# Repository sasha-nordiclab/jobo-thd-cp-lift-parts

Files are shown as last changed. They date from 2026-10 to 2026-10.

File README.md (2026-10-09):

# THD CP-Lift parts

3D-printable parts for working with JOBO drums on the THD CP-Lift. Each part is a parametric FreeCAD model with STEP files and printing notes.

▶ **Videos:** [YouTube playlist](https://www.youtube.com/playlist?list=PLADhkNYpSGAc)

## Downloads

Each link downloads the file directly. STEP files open in any CAD program or slicer. The FCStd files are the parametric FreeCAD models.

| Part | Print files (STEP) | FreeCAD model | Everything in one zip |
|---|---|---|---|
| **Bottle holder** | [Module](https://github.com/sasha-nordiclab/thd-cp-lift-parts/raw/main/bottle-holder/step/THD_CP_Lift_Holder_Module.step) · [Module, mirrored](https://github.com/sasha-nordiclab/thd-cp-lift-parts/raw/main/bottle-holder/step/THD_CP_Lift_Holder_Module_Mirrored.step) · [Nut bar](https://github.com/sasha-nordiclab/thd-cp-lift-parts/raw/main/bottle-holder/step/THD_CP_Lift_Nut_Bar.step) · [Gasket (TPU)](https://github.com/sasha-nordiclab/thd-cp-lift-parts/raw/main/bottle-holder/step/THD_CP_Lift_Gasket_TPU.step) · [Bottle stand (TPU)](https://github.com/sasha-nordiclab/thd-cp-lift-parts/raw/main/bottle-holder/step/THD_CP_Lift_Bottle_Stand_TPU.step) | [FCStd](https://github.com/sasha-nordiclab/thd-cp-lift-parts/raw/main/bottle-holder/cad/THD_CP_Lift_Bottle_Holder.FCStd) | [v1.1 ZIP](https://github.com/sasha-nordiclab/thd-cp-lift-parts/releases/download/bottle-holder-v1.1/bottle-holder-v1.1.zip) |
| **Heater holder** | [Base](https://github.com/sasha-nordiclab/thd-cp-lift-parts/raw/main/heater-holder/step/THD_Heater_Holder_Base.step) · [Cap](https://github.com/sasha-nordiclab/thd-cp-lift-parts/raw/main/heater-holder/step/THD_Heater_Holder_Cap.step) | [FCStd](https://github.com/sasha-nordiclab/thd-cp-lift-parts/raw/main/heater-holder/cad/THD_Heater_Holder.FCStd) | [v1.0 ZIP](https://github.com/sasha-nordiclab/thd-cp-lift-parts/releases/download/heater-holder-v1.0/heater-holder-v1.0.zip) |
| **Drum mount** (experimental) | [Mount](https://github.com/sasha-nordiclab/thd-cp-lift-parts/raw/main/drum-mount/step/JoboDrumMount_Mount.step) · [Lock](https://github.com/sasha-nordiclab/thd-cp-lift-parts/raw/main/drum-mount/step/JoboDrumMount_Lock.step) | [FCStd](https://github.com/sasha-nordiclab/thd-cp-lift-parts/raw/main/drum-mount/cad/JoboDrumMount.FCStd) | [v0.1 ZIP](https://github.com/sasha-nordiclab/thd-cp-lift-parts/releases/download/drum-mount-v0.1/drum-mount-v0.1.zip) |

The whole repository as a zip: [main.zip](https://github.com/sasha-nordiclab/thd-cp-lift-parts/archive/refs/heads/main.zip). Screws, nuts and print settings for each part are in its README.

## Parts

| Part | What it does | Status | Folder |
|---|---|---|---|
| **Bottle holder** | An optimised redesign for this machine: holds four standard JOBO bottles in the water bath. It mounts with stainless countersunk screws through the 3 mm bath wall into a printed nut bar. See the [design report](bottle-holder/docs/report.md); FEM has not been rerun for the latest frame details. | [v1.1 release](https://github.com/sasha-nordiclab/thd-cp-lift-parts/releases/tag/bottle-holder-v1.1) | [`bottle-holder/`](bottle-holder/) |
| **Drum mount** | Holds a JOBO drum on the lift, with a sliding lock and a printed spring. | 🧪 [v0.1 experimental release](https://github.com/sasha-nordiclab/thd-cp-lift-parts/releases/tag/drum-mount-v0.1) | [`drum-mount/`](drum-mount/) |
| **Heater holder** | An ABS clamp that holds the 220 V bath heater horizontally, 15 mm above the bath floor. The base is glued to the floor, and the cap is screwed down with two M4 countersunk Torx screws that form their own thread in the plastic. | [v1.0 release](https://github.com/sasha-nordiclab/thd-cp-lift-parts/releases/tag/heater-holder-v1.0) | [`heater-holder/`](heater-holder/) |

## Shared pump model and accessories

The [ROTEK A01VP repository](https://github.com/sasha-nordiclab/ROTEK-A01VP) holds the parametric reference model of the Rotek circulation pump and compatible accessories, starting with a TPU vibration-damping holder. The same pump is used in the JOBO Repair Parts project. The [FreeCAD model](https://github.com/sasha-nordiclab/ROTEK-A01VP/blob/main/cad/TPU_Pump_Holder.FCStd) contains both the pump and the holder.

<table align="center">
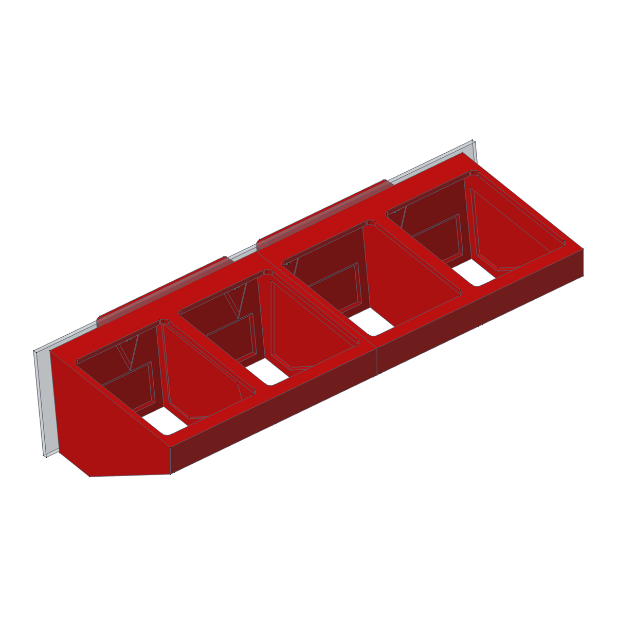
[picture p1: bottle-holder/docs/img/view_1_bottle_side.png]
Bottle holder
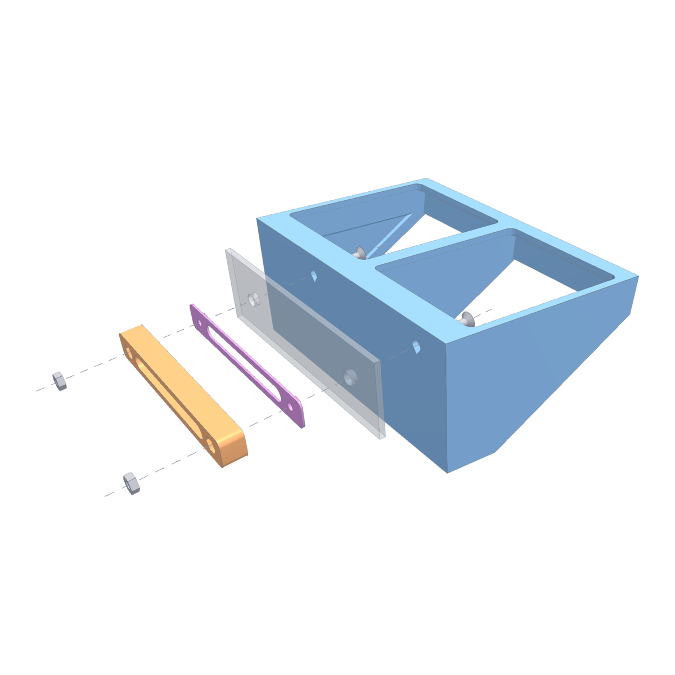
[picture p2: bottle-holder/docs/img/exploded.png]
Exploded view
  <tr><td align="center"><br><b>Bottle holder</b></td><td align="center"><br><b>Exploded view</b></td></tr>
</table>

## Common notes

- **Material:** PETG for the bottle holder and drum mount; ABS for the heater holder.
- **Profile used for the times in each README:** 0.4 mm nozzle, 0.6 mm line width, 0.2 mm layers, 5 walls, OrcaSlicer on a Bambu Lab A1.
- **Models:** made with a FreeCAD 26.3 development build. Older FreeCAD releases may not open them; the STEP files work in any CAD or slicer.
- **Changing sizes:** every model is driven by a spreadsheet (`params` or `Params`). Change the values there and recompute.

## License

[CC BY-NC-SA 4.0](LICENSE). You may share and adapt these designs with attribution, not for commercial use, and under the same license.

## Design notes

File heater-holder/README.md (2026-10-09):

# THD heater holder — ABS clamp

A two-part clamp that holds the 220 V THD bath heater horizontally on the bath floor. The base is glued to the floor. The cap is pulled down onto the soft rubber head of the heater by two M4 screws. The clamp has no snap, so thermal swell of the head or the plastic does not matter.

**Release:** [v1.0](https://github.com/sasha-nordiclab/thd-cp-lift-parts/releases/tag/heater-holder-v1.0). [Download the complete ZIP](https://github.com/sasha-nordiclab/thd-cp-lift-parts/releases/download/heater-holder-v1.0/heater-holder-v1.0.zip).

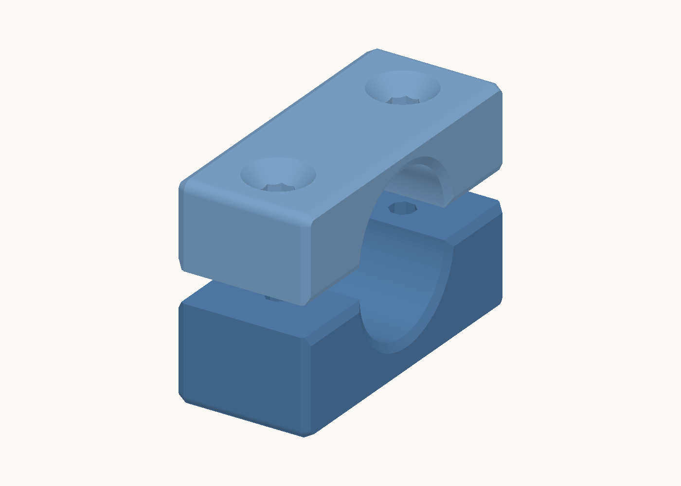
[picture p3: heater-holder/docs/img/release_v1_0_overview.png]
Heater clamp base and cap
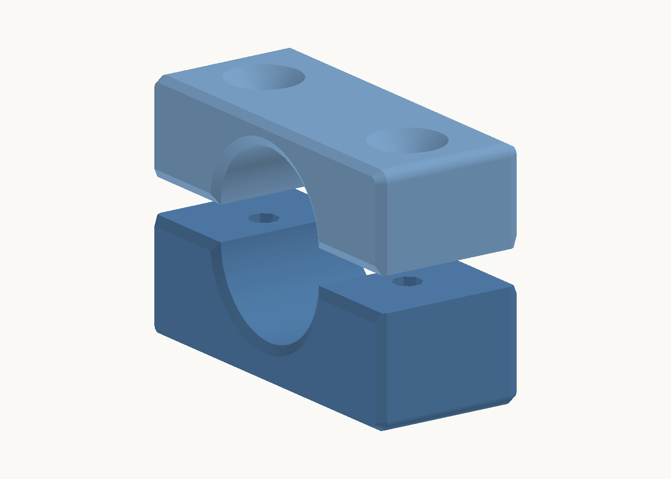
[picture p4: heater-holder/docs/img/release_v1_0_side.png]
Heater clamp from the side


⬇️ **Download:** [Base](https://github.com/sasha-nordiclab/thd-cp-lift-parts/raw/main/heater-holder/step/THD_Heater_Holder_Base.step) · [Cap](https://github.com/sasha-nordiclab/thd-cp-lift-parts/raw/main/heater-holder/step/THD_Heater_Holder_Cap.step) · [FreeCAD model](https://github.com/sasha-nordiclab/thd-cp-lift-parts/raw/main/heater-holder/cad/THD_Heater_Holder.FCStd)

## Model

**Working model:** [THD_Heater_Holder.FCStd](cad/THD_Heater_Holder.FCStd), rebuilt from scratch with `python3 scripts/build.py` (fdmkit over RPC). All sizes are in the `params` spreadsheet.

- Body **Heater**: a reference mock-up. The rod is Ø16 × 110, the rubber head Ø20 × 20.
- Body **Base**: glued to the floor, with a half-round bed for the head.
- Body **Cap**: a plain block with a half-round bore, screwed onto the base.
- **Screw** is an M4 × 25 ISO 14581 (countersunk Torx) from the Fasteners workbench. **Screw_Mirror** is an `App::Link` to it.

### How the model is built

Both parts are symmetric about the vertical plane through the heater axis. Each one is modelled as its +Y half and mirrored once:

| Step | Base | Cap |
|---|---|---|
| 1. Half profile sketch | `s_b_half`: block with a corner round and the half bed | `s_k_half`: block with a corner round and the half bore |
| 2. Pad, symmetric, `c_len` | `b_half` | `k_half` |
| 3. Screw hole on +Y | `b_pilot`: octagonal pilot | `k_oct` and `k_hole`: octagon and countersink (PartDesign Hole) |
| 4. End-face chamfers | `b_bed_chamfer`, `b_top_chamfer` | `k_bed_chamfer`, `k_top_chamfer` |
| 5. Mirror the whole half across XZ | `b_mirror` | `k_mirror` |

The constraints in the half-profile sketches carry readable names, such as `axis_z`, `half_width`, `bore_r` and `cap_top`.

Every sketch is fully constrained, and every size comes from the `params` spreadsheet. Change a value there and recompute. Checked with a 24 mm head, a 25 mm head length, an 18 mm axis height and a 54 mm width.

### Coordinates

- z = 0 is the bath floor, which is also the base's glue face.
- The heater axis runs along X at `ax_z` = 15 mm.
- x = 0 is the joint between head and rod. The head is at x −20…0, the rod at x 0…110.

### Clamp

| | |
|---|---|
| Length along the axis | `c_len` = the full head length, 20 mm |
| Bore | Ø19.8 (`c_fit` 0.2 undersize), split at the axis with a `k_gap` 0.6 mm gap |
| Base | a solid block, 46 × 20 mm on the floor and 14.7 mm high, with a half-round bed |
| Cap | a plain block, 46 × 20 × 12.6 mm, with a half-round bore. Together with the base it makes one rectangular block split at the axis. The outer corners have an R1.5 round (`k_er`) |
| Screws | 2 × M4 × 25 ISO 14581, 304 stainless, at ±14.5 mm. The heads sit flush in 90° countersinks (Ø9.6) |
| Thread | the screws form their own thread in octagonal blind pilot holes in the base: 3.5 mm across flats, 13 mm deep. The screw bites into the flats, and the corners take the chips. Engagement is 11.8 mm |

Tightening the screws closes the gap, so the rubber head is squeezed by about 0.8 mm in height.

The heater bottom is 5 mm above the floor and the rod bottom 7 mm, so water flows under the rod.

## Files

- [cad/THD_Heater_Holder.FCStd](cad/THD_Heater_Holder.FCStd) is the parametric model.
- [`step/`](step/) holds the STEP files of the base and the cap.
- [scripts/build.py](scripts/build.py) rebuilds the model in a running FreeCAD through fdmkit.

## Print

ABS (AzureFilm ABS Plus), profile "0.20mm NordicLab 0.6 Ballance", 100 % zig-zag, Bambu A1:

| Part | Orientation | Time | Mass |
|---|---|---|---|
| Base | on its end face x = −20 (profile on the bed) | 36 min 0 s | 10.2 g |
| Cap | on its end face x = −20 (profile on the bed) | 32 min 30 s | 7.9 g |

ABS warps on the open A1. Both parts have a plain rectangular outline with rounded outer corners. Use a brim.

Every edge of both end faces has a chamfer: 1.2 mm along the print vertical at 30° from vertical, so 0.69 mm on the face (`e_h`, `e_a`). On the bed face it prevents elephant foot. The four outer corners of the block are rounded with R1.5 (`k_er`); they run along the print vertical.

All screw holes are octagons, with a flat facing up in the end-face print: a short bridge (< 2 mm) on top and 45° sides. The cap clearance holes are 4.5 mm across flats. The upper part of the 90° countersink is 45° from vertical, which is slightly over the 40° limit, but it is only about 2.5 mm deep.

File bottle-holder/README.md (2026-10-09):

# THD CP-Lift bottle holder

**Release:** [v1.1](https://github.com/sasha-nordiclab/thd-cp-lift-parts/releases/tag/bottle-holder-v1.1) has the latest pair of frames. The [v1.0 release](https://github.com/sasha-nordiclab/thd-cp-lift-parts/releases/tag/bottle-holder-v1.0) is archived.

⬇️ **Download:** [Module](https://github.com/sasha-nordiclab/thd-cp-lift-parts/raw/main/bottle-holder/step/THD_CP_Lift_Holder_Module.step) · [Module, mirrored](https://github.com/sasha-nordiclab/thd-cp-lift-parts/raw/main/bottle-holder/step/THD_CP_Lift_Holder_Module_Mirrored.step) · [Nut bar](https://github.com/sasha-nordiclab/thd-cp-lift-parts/raw/main/bottle-holder/step/THD_CP_Lift_Nut_Bar.step) · [Gasket (TPU)](https://github.com/sasha-nordiclab/thd-cp-lift-parts/raw/main/bottle-holder/step/THD_CP_Lift_Gasket_TPU.step) · [Bottle stand (TPU)](https://github.com/sasha-nordiclab/thd-cp-lift-parts/raw/main/bottle-holder/step/THD_CP_Lift_Bottle_Stand_TPU.step) · [FreeCAD model](https://github.com/sasha-nordiclab/thd-cp-lift-parts/raw/main/bottle-holder/cad/THD_CP_Lift_Bottle_Holder.FCStd) · [v1.1 ZIP](https://github.com/sasha-nordiclab/thd-cp-lift-parts/releases/download/bottle-holder-v1.1/bottle-holder-v1.1.zip)

An optimised redesign of the bottle holder, reworked for the THD CP-Lift. It holds **four standard JOBO bottles** in the water bath.

- It mounts with stainless steel countersunk screws through the 3 mm bath wall. A printed nut bar on the outside of the bath holds the nuts.
- Each module holds two bottles. Print one **Module**, one **Module mirrored**, two **Nut bars** (PETG), two **Gaskets** and four **Bottle stands** (TPU).

▶ **Videos:** [YouTube playlist](https://www.youtube.com/playlist?list=PLADhkNYpSGAc)

<table align="center">
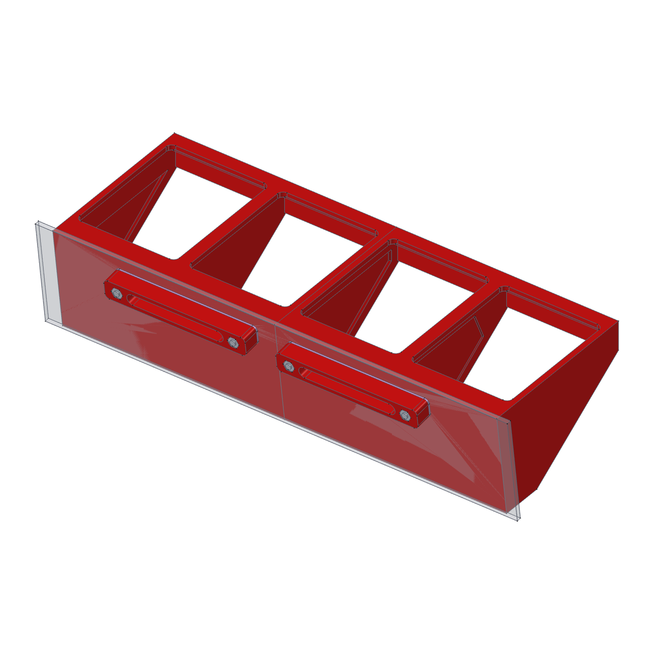
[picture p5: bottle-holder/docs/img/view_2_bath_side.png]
Bath side
  <tr><td align="center">Bottle side<br><b>Bottle side</b></td><td align="center"><br><b>Bath side</b></td></tr>
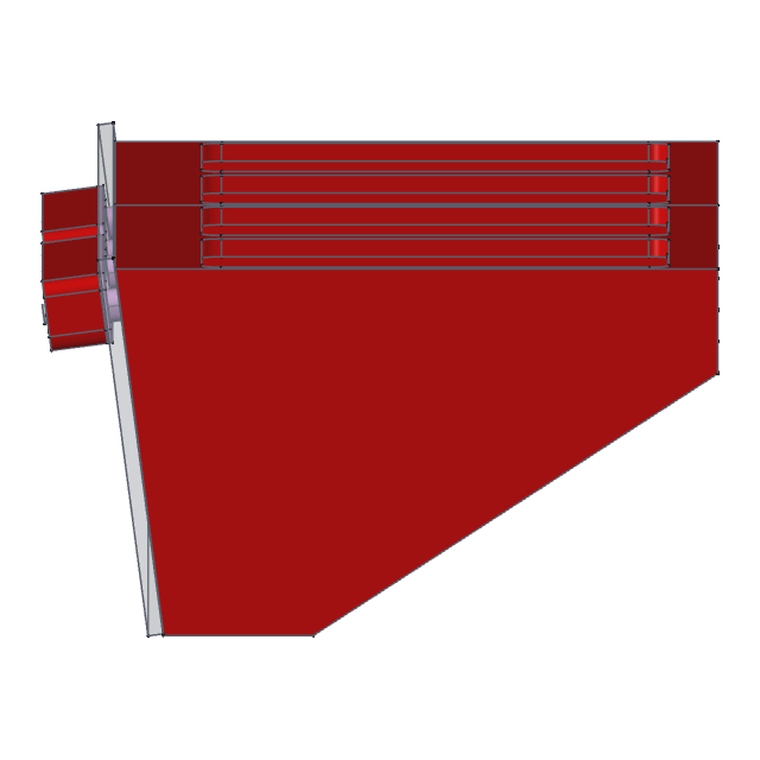
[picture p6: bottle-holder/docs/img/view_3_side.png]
Side
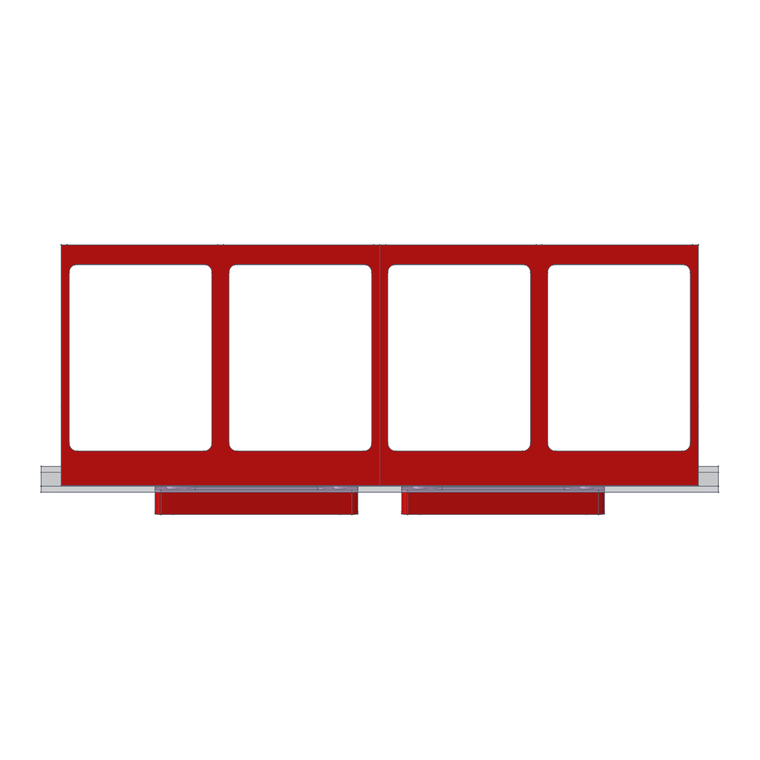
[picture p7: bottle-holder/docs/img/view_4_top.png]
Top
  <tr><td align="center"><br><b>Side</b></td><td align="center"><br><b>Top</b></td></tr>
</table>

Latest frame geometry: [isometric view](docs/img/release_v1_1_overview.png) · [top view](docs/img/release_v1_1_top.png).

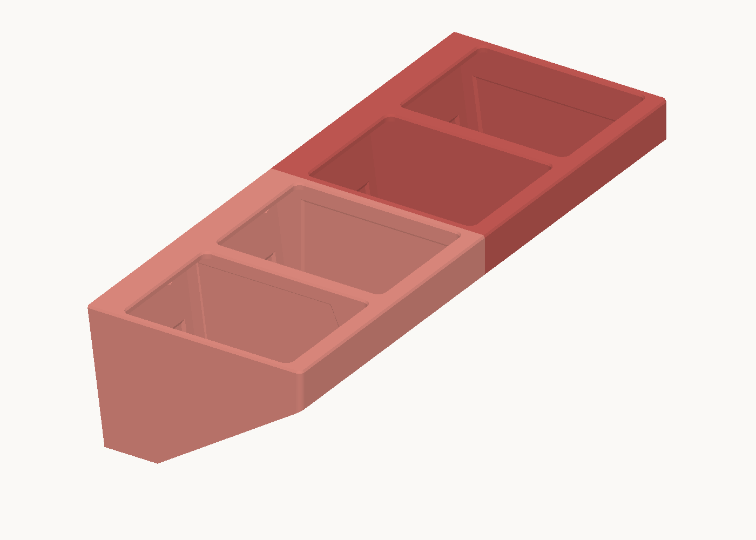
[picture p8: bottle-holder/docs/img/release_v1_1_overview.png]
Current four-bottle frame, made from two mirrored modules


| | Per module |
|---|---|
| Size | 120.4 × 159.5 × 74.7 mm |
| Bottle opening | 93.4 × 71.4 mm, corner radius 4 mm (×2) |
| Mounting | 2 × M4 × 20 countersunk Torx screws (304 stainless) + 2 nuts in a nut bar |
| Material | PETG |
| Mass / print time | ≈ 126 g / ≈ 3 h (solid, see [Printing](#printing)) |

## Files

| Path | What |
|---|---|
| `cad/THD_CP_Lift_Bottle_Holder.FCStd` | Parametric FreeCAD model: bodies `Module`, `Nut_Bar`, `Gasket`, `Bottle_Stand`, the mirrors, and an `Assembly` with the screws, nuts and a reference bath |
| `step/THD_CP_Lift_Holder_Module.step` | Module, for slicing or other CAD |
| `step/THD_CP_Lift_Holder_Module_Mirrored.step` | Mirrored module |
| `step/THD_CP_Lift_Nut_Bar.step` | Nut bar; print two, the same part fits both modules |
| `step/THD_CP_Lift_Gasket_TPU.step` | Gasket under the nut bar; print two in TPU 95A |
| `step/THD_CP_Lift_Bottle_Stand_TPU.step` | Bottle stand glued to the bath floor; print four in TPU 95A |
| `docs/report.md` | Design report: how it works, assembly, calculations, FEM pictures |
| `docs/strength.md` | How the part was checked and why it looks the way it does |
| `scripts/fem/` | The strength calculation (CalculiX), for the default size |

## Printing

- **Orientation:** frame face down on the bed. The top face is flat, and nothing is steeper than 40° except the small screw countersinks. No supports are needed.
- **Profile:** PETG, 0.4 mm nozzle, 0.6 mm line width, 0.2 mm layers, 5 walls.
- **Infill:** **100 %, rectilinear (zig-zag).**
  - The walls are 1.8–3 mm thick and the strength check assumes solid plastic.
  - 5 walls of 0.6 mm fill the 3 mm walls exactly, and 100 % infill makes the 3.6 mm frame solid.
  - On thin-walled parts like this, 100 % rectilinear was faster than 40 % cubic.
- **Result:** in OrcaSlicer on a Bambu Lab A1, about 3 h 05 min and 126 g per module.

| Part | Qty | Material | Orientation | Time / mass each |
|---|---|---|---|---|
| Module, Module mirrored | 1 + 1 | PETG | frame face down | ≈ 3 h 05 min, 126 g |
| Nut bar | 2 | PETG | bath side down, nut pockets up | ≈ 32 min, 11 g |
| Gasket | 2 | TPU 95A | flat, sleeves up, 100 % | ≈ 12 min, 1 g |
| Bottle stand | 4 | TPU 95A | glue face down | ≈ 1 h 16 min, 11 g |

## Bottle stands

A small TPU stand under each bottle, glued to the floor of the bath. The bottle rests on it instead of on the bath floor, so water flows under and around the bottle.

- Rounded frame 45 × 35 mm, 20 mm tall, 2.4 mm walls, with a cross inside.
- **Glue face:** a solid 1.2 mm base, about 1540 mm² of flat surface. The stand is printed on this face, so it is flat and ready for glue.
- **Water flow:** every wall and the cross have windows from the top of the base up to 13 mm. No cell is closed, so water flows straight through and nothing is trapped when the bath is drained.
- The windows have 45° pointed tops, so TPU prints them without supports.
- Position: centred under each bottle opening; the stand's base is 145 mm below the top of the frame (`stand_drop`).
- All sizes are in `params`: `stand_dx`, `stand_dy`, `stand_h`, `stand_r`, `stand_w`, `stand_base`, `stand_win_top`, `stand_drop`.

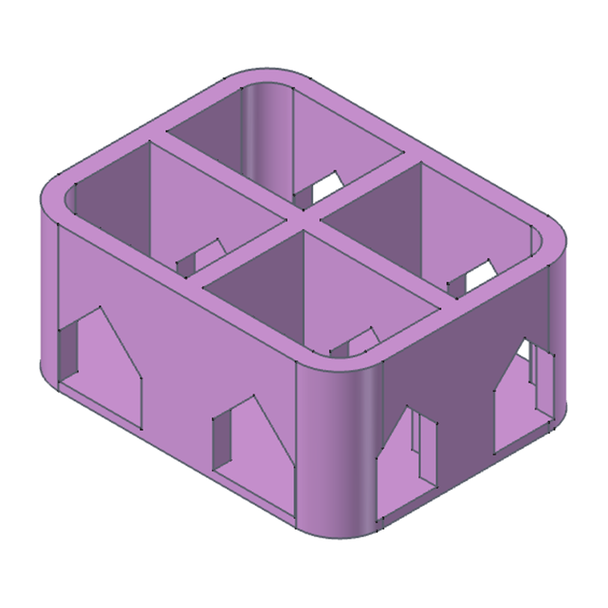
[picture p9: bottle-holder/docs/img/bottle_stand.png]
TPU bottle stand


## Assembly in the model

The FreeCAD file contains an `Assembly` (Assembly workbench) with both modules, the nut bars, the gaskets, the four stands, 4 × M4 × 20 ISO 14581 screws, 4 × M4 ISO 4032 nuts, and a reference bath wall and floor.
- Every position follows the spreadsheet, including the wall tilt, the screw length and the stand depth.
- The screws and nuts come from the **Fasteners** workbench; install it from the Addon Manager to open the assembly.
- In the Fasteners objects the screw length is a fixed 20 mm. If you change `bolt_len`, change it there too.

## Mounting

<p align="center">Exploded view: holder, bath wall, TPU gasket, nut bar, nuts</p>

<p align="center"><a href="docs/img/exploded.mp4">▶ Explode animation</a></p>

**Per module you need:**
- 2 × **M4 × 20 countersunk Torx screws**, 304 stainless (ISO 14581, 90° head Ø 8.4 mm). They fit the Ø 9.2 mm countersink.
- 2 × **M4 nuts** ISO 4032, stainless.
- 1 × **printed nut bar**.
- 1 × **TPU gasket** (between the bath and the nut bar).

The screws go in from the bottle side, through the holder and the bath's Ø 6.6 mm holes. The nuts sit in the hex pockets of the nut bar on the outside of the bath.

**The stack along the screw:**

| Part of the stack | mm |
|---|---|
| Head top to the holder's mounting face | 4.0 |
| Bath wall | 3.0 |
| TPU gasket | 1.0 |
| Nut bar under the nut | 7.9 |
| Nut ISO 4032, flush in its pocket | 3.2 + 0.2 |
| Screw tip past the nut | 0.9 |
| **Total** | **20** |

The nut bar is sized to the screw. `bolt_len` in the spreadsheet sets the screw length, and the bar thickness follows (11.3 mm for M4 × 20 with the 1 mm gasket, at least 5.4 mm). The tip then ends just past the nut and does not stick out behind the bath; `bolt_tip` shows the overhang.

- **Sealing the bath holes.** A flat 1 mm TPU 95A gasket with the same outline as the nut bar goes between the bar and the outside of the bath wall. Tightening squeezes it.
  - A Ø 6.3 mm sleeve on the gasket goes into each Ø 6.6 mm bath hole; the screw passes through a Ø 4.2 mm hole in it.
  - The holder itself is unchanged, so its strength check still applies. The bath pressure is tiny (0.01–0.02 bar).
  - Print the gasket flat, sleeves up, 100 % infill.
- The bath holes are a standard M6 clearance (6.6 mm). The M4 screws have play in them, but the countersunk heads and the nut bar hold everything in place.
- The rear face of the holder is tilted 7.5° to sit flat on the bath wall.
- Each bottle's side rib catches the ledge under the front of the frame, so a floating bottle cannot lift out.
- The nut bar has a through slot between the nuts, so material stays only where the nuts press; `slot_w` and `slot_off` set it.
- Print the nut bar flat, bath side down, with the pockets facing up: about 32 min and 11.4 g.

## Adapting it to other bottles

Open the model in FreeCAD and edit the spreadsheet `params`. Everything else, including the nut bar, follows these five values:

| Parameter | Default | Meaning |
|---|---|---|
| `open_x` | 93.4 | bottle opening, rear to front |
| `open_y` | 71.4 | bottle opening, side to side |
| `open_r` | 4 | opening corner radius |
| `web_h` | 70.5 | depth of the side walls below the frame |
| `lip_h` | 18 | depth of the front wall |

**Bath wall tilt.** If your bath wall leans differently, change `rear_tilt` (default 7.5°, 0 = vertical). The whole rear wall, the frame edge, the screw holes and bosses, the recesses, the nut bar and the gasket all follow. Rebuilds were checked at 0°, 3°, 7.5°, 10° and 15°: the mounting face stays one flat plane and the screw length is unchanged.

What follows automatically:
- the bay pitch, module length, frame, recesses, screw positions and the mirror;
- recesses switch themselves off when their zone gets too small;
- the screws keep clear of the walls.

**Other parameter groups in `params`:**
- **Build:** wall and frame thickness, gaps.
- **Mount:** wall tilt, screw positions, bosses.
- **Lightening:** recess depths (0 = none).
- **Nut bar:** bath wall, nut size, bar thickness and width, plus the screw length `bolt_len`.

Do not edit the **Derived** cells.

These sizes were rebuilt and checked: 50 × 40 / 35 mm, 60 × 45 / 45 mm, 75 × 60 / 60 mm, 100 × 80 / 80 mm, and 2.4 mm walls. In every case the result is one valid solid with clear screw holes. **Strength was calculated only for the default size**; check yours before relying on it.

The model was made with a FreeCAD 26.3 development build. Older FreeCAD releases may not open it; the STEP files work anywhere.

## Strength

The finite-element calculation predates the latest hole layout and frame chamfer; it has not been rerun for this revision.

Checked by finite elements (CalculiX) with real supports:
- the screw heads clamp the countersinks;
- the rear wall can push on the lift wall but not pull;
- the material is treated as layered PETG, so layers can peel apart.

Loads:
- floating empty bottles, sustained, safety factor 4;
- a full 0.7 kg bottle knocked into the part at 0.5 m/s, safety factor 2.

| Load case | Load / allowable |
|---|---|
| Floating bottles (sustained) | 0.31 ✅ |
| Bottle hits the frame from above | 1.08 |
| Bottle hits the front edge | 1.17 |
| Bottle hits the divider sideways | 1.75 |

- A value of 1.0 or less passes with the full safety factor.
- Values up to 2 use part of the safety factor of 2 but stay below the material strength. The worst case is a sideways knock on the divider, at the corner of the opening.
- The front ledge and overall layout come from a holder that is already in use.

Deformation under each load, strongly exaggerated (colour = deflection, arrows = load):

<table align="center">
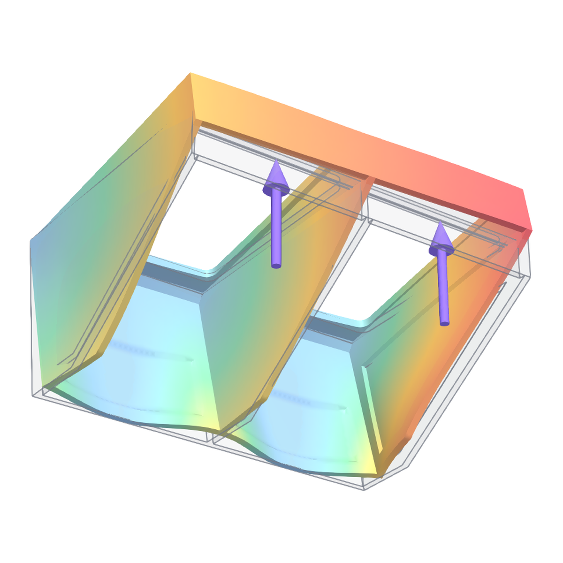
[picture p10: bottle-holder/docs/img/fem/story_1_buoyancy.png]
Floating bottles
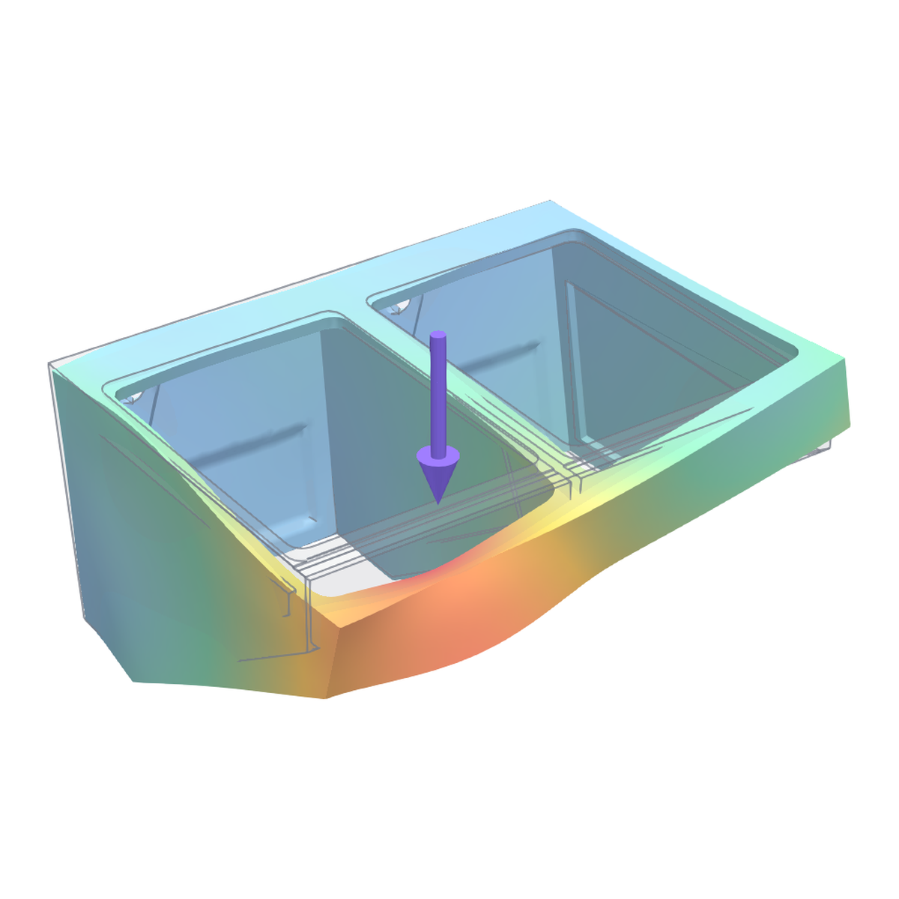
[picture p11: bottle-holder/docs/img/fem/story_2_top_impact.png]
Hit from above
  <tr><td align="center"><br><b>Floating bottles</b></td><td align="center"><br><b>Hit from above</b></td></tr>
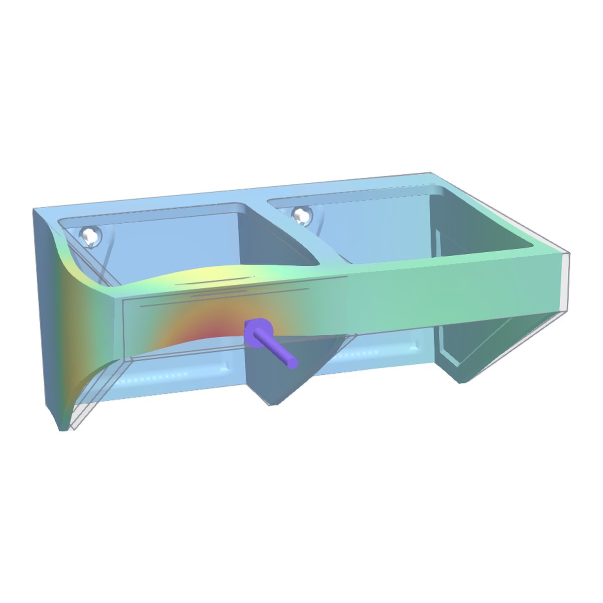
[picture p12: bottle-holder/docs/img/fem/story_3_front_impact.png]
Hit on the front edge
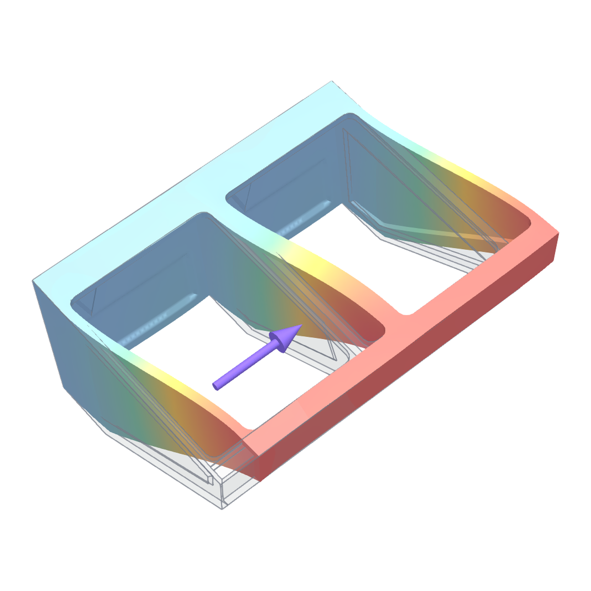
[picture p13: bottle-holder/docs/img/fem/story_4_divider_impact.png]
Hit on the divider
  <tr><td align="center"><br><b>Hit on the front edge</b></td><td align="center"><br><b>Hit on the divider</b></td></tr>
</table>

<p align="center"><a href="docs/img/fem/loads_story.mp4">▶ Animation of all four load cases</a></p>

The full design report (how it works, exploded view, screw and seal calculations, deformation pictures) is in [docs/report.md](docs/report.md). The method, the design changes and the rejected variants are in [docs/strength.md](docs/strength.md).

## License

[CC BY-NC-SA 4.0](../LICENSE): you may share and adapt this design with attribution, not for commercial use, and under the same license.

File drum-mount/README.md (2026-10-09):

# JOBO drum mount for the THD CP-Lift

> [!WARNING]
> **Experimental, work in progress.** The geometry may change, and it has not been strength-checked. Print and use it at your own risk.

**Experimental release:** [v0.1](https://github.com/sasha-nordiclab/thd-cp-lift-parts/releases/tag/drum-mount-v0.1). [Download the complete ZIP](https://github.com/sasha-nordiclab/thd-cp-lift-parts/releases/download/drum-mount-v0.1/drum-mount-v0.1.zip).

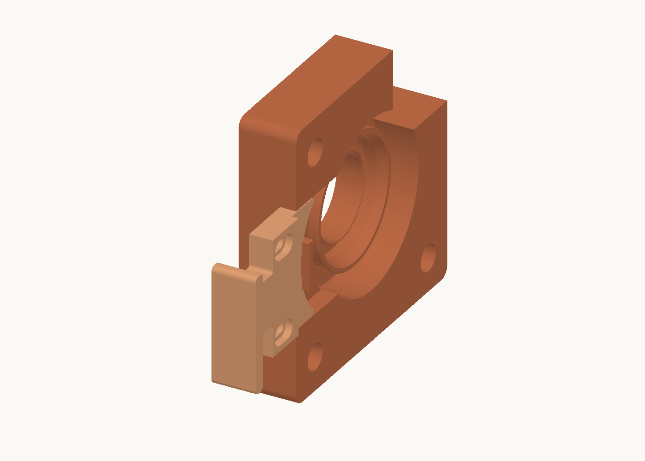
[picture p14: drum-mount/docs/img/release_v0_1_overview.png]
Drum mount and sliding lock
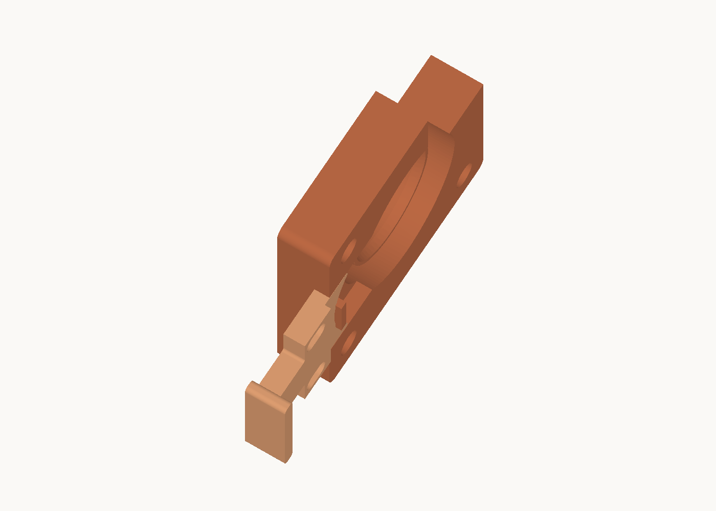
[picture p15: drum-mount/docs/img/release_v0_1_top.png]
Drum mount and lock from above


⬇️ **Download:** [Mount](https://github.com/sasha-nordiclab/thd-cp-lift-parts/raw/main/drum-mount/step/JoboDrumMount_Mount.step) · [Lock](https://github.com/sasha-nordiclab/thd-cp-lift-parts/raw/main/drum-mount/step/JoboDrumMount_Lock.step) · [FreeCAD model](https://github.com/sasha-nordiclab/thd-cp-lift-parts/raw/main/drum-mount/cad/JoboDrumMount.FCStd)

A two-part mount that holds a JOBO drum on the THD CP-Lift:
- **Mount** — an 80 × 80 mm plate with locating rings, a Ø 24 mm centre bore and a pocket for the motor.
- **Lock** — a sliding latch with a printed spring. To release the drum, pull the finger ears; the spring pushes the latch back. Travel is 3.5 mm.

| Part | Size | Print (PETG, see below) |
|---|---|---|
| Mount | 80 × 80 × 19 mm | ≈ 2 h, 60 g (40 % infill) / 85 g (solid) |
| Lock | 45 × 34 × 13 mm | ≈ 25 min, 8 g |

## Files

| Path | What |
|---|---|
| `cad/JoboDrumMount.FCStd` | Parametric FreeCAD model: bodies `Mount` and `Lock`, the final `LockMirror` feature, and an assembly that shows how they fit |
| `step/JoboDrumMount_Mount.step` | Mount |
| `step/JoboDrumMount_Lock.step` | Lock, exported from `LockMirror` |

## Printing

- Both parts print flat on their largest face, with no supports.
- PETG, 0.4 mm nozzle, 0.6 mm line width, 0.2 mm layers, 5 walls.
- The times above are from OrcaSlicer on a Bambu Lab A1. The Mount at 40 % cubic is enough for normal use; print it solid if you want it stiffer.

## Assembly

- **Mount to the lift:** three screws through Ø 4.5 mm holes with Ø 8 mm counterbores, 4.4 mm deep. M4 cap screws fit.
- **Lock to the Mount:** two screws through the Lock's slots into Ø 2.9 mm pilot holes in the Mount. M3 screws tap into them.

## Parameters

All sizes are in the spreadsheet `Params`. Cells starting with `D_` are derived; do not edit them.

| Parameter | Default | Meaning |
|---|---|---|
| `PLATE_W`, `PLATE_T`, `PLATE_R` | 80, 5, 3 | plate width, thickness, corner radius |
| `RING_OD`, `RING_ID`, `RING_H` | 39, 34, 7 | locating ring |
| `RING2_OD`, `RING2_H` | 26, 3 | inner ring |
| `BORE_D` | 24 | centre bore |
| `RECESS_D`, `FRAME_H` | 50, 12 | drum recess diameter, frame height |
| `MOTOR_OFS`, `MOTOR_POCKET_R` | 31.5, 11 | motor pocket position and radius |
| `HOLE_OFS`, `HOLE_D`, `HOLE_CB_D`, `HOLE_CB_DEPTH` | 30, 4.5, 8, 4.4 | mounting holes |
| `SLOT_W`, `LOCK_CLR`, `LOCK_TRAVEL` | 35, 0.3, 3.5 | lock slot width, clearance, travel |
| `SPRING_T`, `SPRING_PRE` | 1.3, 0.5 | spring strip thickness, preload |
| `LOCK_SCREW_PITCH`, `LOCK_SCREW_HOLE_D` | 25, 2.9 | lock screws |

## License

[CC BY-NC-SA 4.0](../LICENSE).

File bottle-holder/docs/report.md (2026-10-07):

# THD CP-Lift bottle holder — design report

Revision: 2026-10-06. Covers the bottle holder, its mounting (nut bar, TPU gasket, screws) and the checks behind each decision.

<p align="center">Two modules on the bath wall: four bottles</p>

## 1. Summary

**What it is.** A printed holder for **four standard JOBO bottles** in the water bath of the THD CP-Lift.
- It is made of two modules: a **Module** and its mirror image. Each holds two bottles.
- Each module screws through the 3 mm bath wall with two stainless countersunk screws.
- On the outside of the bath, a printed **nut bar** holds the nuts and a **TPU gasket** seals the holes.

**Key numbers per module:**

| | |
|---|---|
| Size | 120.4 × 159.5 × 73.5 mm |
| Holder | 102.6 cm³, ≈ 126 g PETG, ≈ 3 h 05 min (solid) |
| Nut bar | 101.5 × 14 × 11.3 mm, ≈ 11 g PETG, ≈ 32 min |
| Gasket | 1 mm TPU 95A, ≈ 1 g |
| Hardware | 2 × M4 × 20 countersunk Torx (304 stainless), 2 × M4 nut ISO 4032 |
| Strength (load / allowable, ≤ 1 passes) | floating bottles **0.31** ✅; knocks by a full bottle 1.08–1.75 (see §5) |

## 2. How it works

<p align="center">Exploded view: holder, bath wall, TPU gasket, nut bar, nuts</p>

[Explode animation](img/exploded.mp4)

**Holding the bottles.**
- Each bottle drops through a rounded opening in the top frame.
- Its side rib catches a ledge under the front edge of the frame.
- An empty or half-full bottle floats in the bath. Buoyancy pushes the rib up against the ledge, so the bottle cannot lift out.

**Carrying the load into the bath wall.**
- The holder is a shelf hanging on the bath wall. The bottle loads push the front down or up, and that creates a moment at the wall.
- The moment is carried in two ways: the two screws near the top hold the holder against the wall, and the rear face bears on the wall over its whole height.
- The rear face is one flat surface tilted 7.5°, the same angle as the bath wall, from the bottom of the holder to the top of the frame. The holder therefore bears on the bath wall everywhere and never rocks on an edge.

**The screw joint.** The parts along each screw, from the inside of the bath to the outside:
1. **Screw head.** A countersunk head sits in a 90° Ø 9.2 mm countersink in a teardrop-shaped boss on the holder's rear wall. The boss spreads the screw load downwards, away from the thin wall.
2. **Holder rear wall.** About 4.4 mm of plastic along the screw.
3. **Bath wall.** 3 mm thick, with Ø 6.6 mm holes (M6 clearance). The M4 screw has play there; the clamped joint, not the hole, holds the position.
4. **TPU gasket.** 1 mm thick, the same outline as the nut bar. Its sleeves fill the bath holes from outside, and tightening squeezes it flat against the bath, which seals the holes.
5. **Nut bar.** A PETG bar with hex pockets for the nuts. It spreads the clamp over the bath wall, bridges the Ø 6.6 mm holes and holds the nuts while the screws are turned. A slot between the nuts removes material that carries no load.
6. **Nut.** An M4 ISO 4032 nut, flush in its pocket. The screw tip ends 0.9 mm past it, so nothing sharp sticks out behind the bath.

**Mirrored modules.** The second module is a mirror image, not a copy: its screws sit at mirrored positions. In the CAD file the mirror is generated from the Module, so a change to one updates both. The nut bar and gasket are symmetric, so the same parts fit both modules.

## 3. Parts and hardware

| Part | Qty (4 bottles) | Material | Print |
|---|---|---|---|
| Module | 1 | PETG | frame face down, 5 walls, 100 % zig-zag: ≈ 3 h 05 min, 126 g |
| Module mirrored | 1 | PETG | same |
| Nut bar | 2 | PETG | bath side down, pockets up: ≈ 32 min, 11 g |
| Gasket | 2 | TPU 95A | flat, sleeves up, 100 % |
| Bottle stand | 4 | TPU 95A | glue face down: ≈ 1 h 16 min, 11 g; glued to the bath floor under each bottle |
| Countersunk Torx screw M4 × 20, 304 stainless | 4 | — | — |
| Nut M4 ISO 4032, stainless | 4 | — | — |

The print times are from OrcaSlicer on a Bambu Lab A1: 0.4 mm nozzle, 0.6 mm lines, 0.2 mm layers.

## 4. Assembly

1. Push a gasket onto the outside of the bath wall, with its sleeves in the two holes.
2. Put the nuts into the hex pockets of the nut bar and hold the bar against the gasket.
3. From the bath side, put the holder against the wall and insert the screws through the holder, the bath, the gasket and the bar.
4. Tighten to about **0.5 N·m**: snug with a screwdriver, no force. See §6 for why.
5. Repeat with the mirrored module.
6. After the first warm-up of the bath, check the screws again. PETG settles slightly at 38 °C.

## 5. Strength of the holder (FEM)

**Model.**
- Second-order tetrahedra (Gmsh), solved in CalculiX. PETG: E = 2200 MPa, ν = 0.38.
- **Screws:** the countersink under each head is held fixed. A tightened screw keeps the joint closed (§6), so the seat acts as bonded.
- **Bath wall:** a rigid plate on the tilted mounting plane. The holder's rear face is in frictionless contact with it (CalculiX node-to-surface contact): the wall can push the holder but cannot pull it.
- **Failure criterion:** layered PETG, printed frame-down:

```
FI = sqrt( (σ_vM,in-plane / 40)² + (max(σ_zz, 0) / 20)² + (τ_interlayer / 15)² )    [MPa]
```

  - Strengths are reduced by 0.85 for the 38 °C bath.
  - Safety factor 4 for the sustained load, 2 for knocks.
  - The tables give the load divided by the allowable: **1.0 or less passes**.
- **Knocks:** a full 0.7 kg bottle at 0.5 m/s carries E = 87.5 N·mm. The force follows from the stiffness k at the point of impact: F = √(2 E k).

**Loads and results:**

| Case | Force | Stiffness | Deflection | Load / allowable | Where, failure mode |
|---|---|---|---|---|---|
| Floating bottles, sustained | 2 × 5.9 N up | — | 0.26 mm | **0.31** ✅ | lower rear wall below screw 2; layer peel |
| Full bottle hits the frame from above | 172 N | 169 N/mm | 1.0 mm | 1.08 | rear wall 6 mm beside screw 1; layer peel |
| Full bottle hits the front edge | 136 N | 105 N/mm | 1.3 mm | 1.17 | frame at the front edge; in-plane |
| Full bottle hits the divider sideways | 58 N | 19 N/mm | 3.0 mm | 1.75 | corner of the bottle opening; in-plane |

**What the numbers mean.**
- The sustained load uses less than a third of the allowable, so the holder does not creep in warm water.
- Knocks use part of the safety factor of 2. Even the worst one, 1.75, stays below the material strength: about 0.9 of what warm PETG takes.
- The divider is the softest place: it is a thin wall loaded sideways. A careless sideways knock is the one case to avoid.

**Check of the calculation.** For every case the forces balance:
- applied load + screw reactions + wall reaction = 0;
- the wall reaction points exactly along the wall normal (z/x = 0.1317 = tan 7.5°), as it must without friction.

The floating case stalled at 58 % of the load (one node kept flipping between touching and not touching). Frictionless contact with no initial gap is proportional to the load, so the last converged step was scaled to the full load.

**Correction to earlier results.** An earlier version of the calculation found only 204 nodes on the rear face, out of 10 743: the search tolerance was too tight and the tilt was 7.547° instead of 7.5°. The wall then held the holder on a narrow strip only, so the holder seemed much softer and weaker (hit from above 1.98, floating 0.86). With the whole face in contact, the holder is stiffer. A knock therefore produces a larger force (172 N instead of 43 N), but the stress is lower.

<table align="center">
  <tr><td align="center">Floating bottles<br><b>Floating bottles</b></td><td align="center">Hit from above<br><b>Hit from above</b></td></tr>
  <tr><td align="center">Hit on the front edge<br><b>Hit on the front edge</b></td><td align="center">Hit on the divider<br><b>Hit on the divider</b></td></tr>
</table>

The pictures show the deformed shape, strongly exaggerated, over the undeformed outline. Colour shows deflection, from blue (none) to red (most). The arrows mark the load.

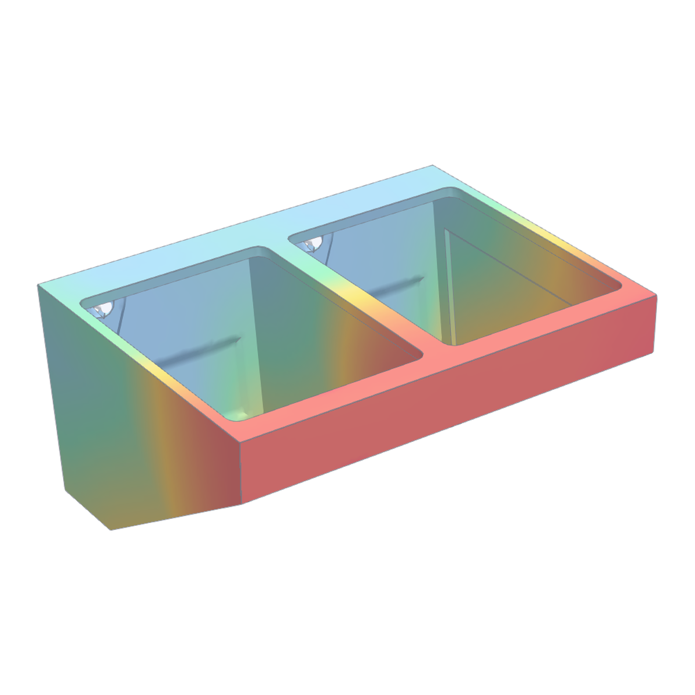
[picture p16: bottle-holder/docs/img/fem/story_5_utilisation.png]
Deflection envelope of all four cases


[Animation of the four load cases](img/fem/loads_story.mp4)

All numbers: [`fem_results.json`](fem_results.json). Method in detail: [`strength.md`](strength.md).

## 6. Screw joint

**Screw length.** The stack along the screw:

| Part of the stack | mm |
|---|---|
| Head top to the holder's mounting face (ISO 14581 head, Ø 8.4 mm) | 4.0 |
| Bath wall | 3.0 |
| TPU gasket | 1.0 |
| Nut bar under the nut | 7.9 |
| Nut + pocket clearance | 3.2 + 0.2 |
| Thread past the nut | 0.9 |
| **Total** | **20 → M4 × 20** |

A 10 mm screw ends 2.7 mm past the bath wall, too short even for a bare nut. In the CAD file, `bolt_len` drives the bar thickness and `bolt_tip` shows the thread past the nut.

**Preload and bearing pressure** at 0.5 N·m (nut factor K ≈ 0.2):

| | Value |
|---|---|
| Preload F = T / (K·d) | ≈ 625 N per screw |
| Screw stress (A_s = 8.78 mm²) | 71 MPa: a small fraction of 304 stainless (≈ 450 MPa proof for A2-70) |
| Head on the countersink (Ø 6 → 8.4 mm, 27 mm²) | 23 MPa |
| Nut on the bar (hex 7 mm minus Ø 4.5, 26.5 mm²) | 24 MPa |

About 20 MPa is what PETG takes long-term at bath temperature without creeping. **Tighten gently.** Over-tightening crushes the plastic under the head and the nut and loosens the joint over time. The thickness of the bar does not change this; the pressure is set by the area under the head and the nut.

**Service loads at the screws** from the FEM:

| Case | Screw 1, axial / lateral | Screw 2, axial / lateral |
|---|---|---|
| Floating bottles | 16 / 4 N | 16 / 8 N |
| Hit from above | **201 / 122 N** | 108 / 49 N |
| Hit on the front edge | 9 / 17 N | 29 / 13 N |
| Hit on the divider | 40 / 27 N | 13 / 33 N |

Screw 1 is in the bay at the end wall, screw 2 in the bay at the far wall. The rest of the moment goes into the bath wall as pressure on the rear face: up to 332 N in a hit from above.

All of them are well below the 625 N preload, so the joint never opens. Lateral loads are carried by friction from the preload (μ ≈ 0.3 → ≈ 190 N per screw) and, beyond that, by the screw shank.

## 7. Sealing

| | Value |
|---|---|
| Water pressure at 20 cm depth | 0.002 MPa |
| Gasket contact pressure, 2 × 625 N over ≈ 846 mm² | ≈ 1.5 MPa |
| Ratio | ≈ 700 × |

The gasket is pressed on several hundred times harder than the water pushes. Its sleeves fill the gap between the M4 screw and the Ø 6.6 mm hole.
- Print it in TPU 95A at 100 % infill so it is fully dense and watertight.
- Replace it if it takes a permanent set.

## 8. Printing

- **Material:** PETG for the holder and the nut bar, TPU 95A for the gasket.
- **Holder orientation:** frame face down. The top face is flat, and nothing is steeper than 40° from vertical except the screw countersinks. No supports are needed.
- **Solid parts:** 5 walls of 0.6 mm fill a 3 mm wall exactly. With 100 % rectilinear infill the frame is solid too, which matches the strength check. It was also faster than 40 % cubic: 3 h 05 min against 3 h 17 min.
- **Recesses instead of windows:** the walls are lightened with one-sided recesses (≥ 1.8 mm left, = 3 lines) instead of through windows. That saves 23 min per module at the same mass.

## 9. Design history and decisions

| Step | Why |
|---|---|
| Through diamond windows → tapered one-sided recesses | Same mass, 23 min faster. Each window in a 3 mm wall adds perimeters and travel. |
| Recess depths from the FEM utilisation map | Thin only where the load is low; never below 3 lines (1.8 mm). |
| 4 mm fill along the rear-wall / frame junction | Removed the layer peel at the junction under buoyancy. |
| Teardrop screw bosses | Moved the stiffness step away from the screw; peak under a hit from above −20 %. |
| One flat tilted mounting face | The vertical frame edge used to stick 0.43 mm out of the tilted face. |
| Fully parametric model | One spreadsheet drives every sketch; tested from 50 × 40 to 100 × 80 mm openings. |
| Nut bar with slot, M4 × 20 | Nuts held captive; slot −40 % plastic; bar thickness follows the screw length. |
| Flat TPU gasket with sleeves | Seals the bath holes; no groove in the holder, so its strength is unchanged. |

**Tried and rejected:**
- ribs under the screws (new peaks at the rib ends);
- local pads around the screws;
- a thicker rear wall (9 g for less gain than the teardrop bosses);
- a TPU washer under the nut (makes the joint soft and lets it loosen);
- a sealing groove in the holder (weakens the area round the screw).

## 10. Limits and open points

- Strength was calculated for the default size only. After changing the bottle size, run the calculation again.
- The recessed version has not yet been printed and tested; the layout and the ledge come from a holder that is already in use.
- PETG strengths are typical values, not tested on this printer. Check a first print under load before relying on it.

## 11. Files

| Path | What |
|---|---|
| `../cad/THD_CP_Lift_Bottle_Holder.FCStd` | Parametric model: Module, Nut bar, Gasket, Bottle stand, their mirrors, and the Assembly |
| `../step/` | STEP of every printed part |
| `strength.md` | FEM method in detail |
| `../scripts/fem/` | Calculation scripts (CalculiX, Gmsh) |
| `img/` | Images and animations in this report |

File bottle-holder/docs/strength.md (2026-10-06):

# Strength check and design decisions

The goal was a holder that is strong where it needs to be, prints fast, and uses plastic only where the load needs it. This page explains how the default size was checked and why the part looks the way it does.

## Model

**Mesh and solver.** Second-order tetrahedra (Gmsh, `-order 2`, `Mesh.SecondOrderLinear 1`, maximum element size 2.5 mm). The solver is CalculiX, linear elastic, with PETG at E = 2200 MPa and ν = 0.38.

**Screws.** The screws are tightened, so the joint stays closed while the load changes the screw force by less than the preload.
- The countersink surface under each screw head is fixed.
- The 6 mm bore has clearance and carries nothing.
- Check after solving: the largest screw force is 201 N axial and 122 N lateral (hit from above). Both are below the 625 N preload and the ≈ 190 N friction it provides, so the joint stays closed.

**Bath wall.** The rear face is in frictionless one-sided contact with the bath wall: the wall can push the part but not pull it.
- The wall is a rigid hexahedral plate on the tilted mounting plane.
- CalculiX solves the contact itself: node-to-surface, linear penalty 2·10⁴ MPa/mm, `ADJUST=0.002` to close round-off gaps.
- All 10 743 nodes of the rear face take part.
- The impacts are solved at 100 N and scaled to the impact force; the floating case at its real load. Frictionless contact with no initial gap is proportional to the load, so the scaling is exact.
- The floating case stalls at 58 % of the load (one node flips between touching and not touching). The last converged step is scaled to the full load.

**Check of every solve.** Applied load + screw reactions + wall reaction = 0, and the wall reaction points along the wall normal (z/x = tan 7.5°).

An earlier version used its own active-set loop and found only 204 face nodes: the tolerance was too tight and the plane was tilted 7.547° instead of 7.5°. The holder then bore on a narrow strip only, which made it look softer and weaker. The numbers below replace those results.

**Failure criterion.** The part is printed frame-down, so the layers lie normal to the model Z axis, and the criterion follows them:

```
FI = sqrt( (σ_vM,in-plane / 40)² + (max(σ_zz, 0) / 20)² + (τ_interlayer / 15)² )    [MPa]
```

- The strengths are typical PETG values: 40 MPa in plane, 20 MPa layer tension, 15 MPa layer shear.
- They are reduced by 0.85 for a 38 °C bath.
- The safety factors are 4 for the sustained load and 2 for impacts.
- The tables report FI divided by the allowable: 1.0 or less passes.

## Loads

| Case | Load |
|---|---|
| Floating bottles | 2 × 5.9 N upwards on the front ledge: an empty 600 ml bottle in water; sustained load |
| Hit from above | A full bottle (0.7 kg) at 0.5 m/s straight down on the front of the frame |
| Hit on the front edge | The same bottle into the front face |
| Hit on the divider | The same bottle sideways into the divider |

Each impact is turned into a force by its energy. With E = ½ m v² = 87.5 N·mm, the force is F = √(2 E k), where k is the stiffness at the point of impact. A stiffer part therefore takes a larger force: stress grows like √k, so "more material" helps less than expected.

## Results (default size)

| Case | Force | Load / allowable | Where |
|---|---|---|---|
| Floating bottles | 11.8 N | **0.31** ✅ | layer peel in the lower rear wall below screw 2 |
| Hit from above | 172 N (k = 169 N/mm) | 1.08 | layer peel in the rear wall beside screw 1 |
| Hit on the front edge | 136 N (k = 105 N/mm) | 1.17 | frame at the front edge |
| Hit on the divider | 58 N (k = 19 N/mm) | 1.75 | corner of the bottle opening |

With the whole rear face in contact, the holder is much stiffer under a hit from above (169 instead of 8 N/mm). A knock therefore produces a larger force, but a lower stress.

On the old strip-contact model, a finer mesh (maximum element size 1.8 mm) raised the peaks by 10–12 %. Expect a similar margin here.

The design changes below were compared on the old strip-contact model. Their ranking holds, but the absolute numbers are from that model.

## What changed against the previous version, and why

| Change | Effect |
|---|---|
| Diamond through-windows replaced by one-sided tapered recesses | Same mass, **23 min faster** to print. Each window in a 3 mm wall adds perimeters and travel moves. |
| Recesses only where the calculated load is low | End wall and far wall 1.8 mm thick, divider 2.4 mm, lower half of the rear wall 1.8 mm. The load in the recess zones is ≤ 0.56 of the allowable. The walls are multiples of the 0.6 mm line width and never thinner than 3 lines. |
| Recess sides tapered at 50° | They overhang no more than 40° from vertical when printed. |
| 4 mm fill along the rear-wall / frame junction | Floating case 1.04 → 0.84 for 0.2 g. |
| Screw bosses extended 22 mm downwards as a teardrop | Hit from above 2.59 → 1.98 for 0.4 g. The boss edge was the stress raiser. |

## Tried and rejected

| Variant | Result |
|---|---|
| Ribs under the screws | Worse: a new peak at the rib end (hit from above 3.26) |
| Local pads around the screws, 1.2 / 2.0 mm | Hit from above 3.05 / 2.29; the floating case got worse |
| Whole rear wall 1 mm thicker | Hit from above 2.05 for 9 g; the teardrop bosses do better for 0.4 g |
| One-sided screw seat without preload | The part becomes a mechanism; wrong for a tightened screw |

## Running the calculation

The scripts in `scripts/fem/` are written for the default size: screw positions and load patches are coordinates in `fem_run.py` and `fem2.py`. They need the Gmsh and CalculiX that ship with FreeCAD. Set `CCX` if CalculiX is not at the macOS default path.

```sh
gmsh module.step -3 -order 2 -setnumber Mesh.SecondOrderLinear 1 -clmax 2.5 -clmin 0.8 -format inp -o module.inp
CASES=BUOY,HIT_TOP,HIT_FRONT,HIT_DIVIDER python3 scripts/fem/fem6.py module.inp result   # 10-30 min per case
```

Export `module.step` from the `Module` body with its placement reset to identity. The model coordinates are those of the body.

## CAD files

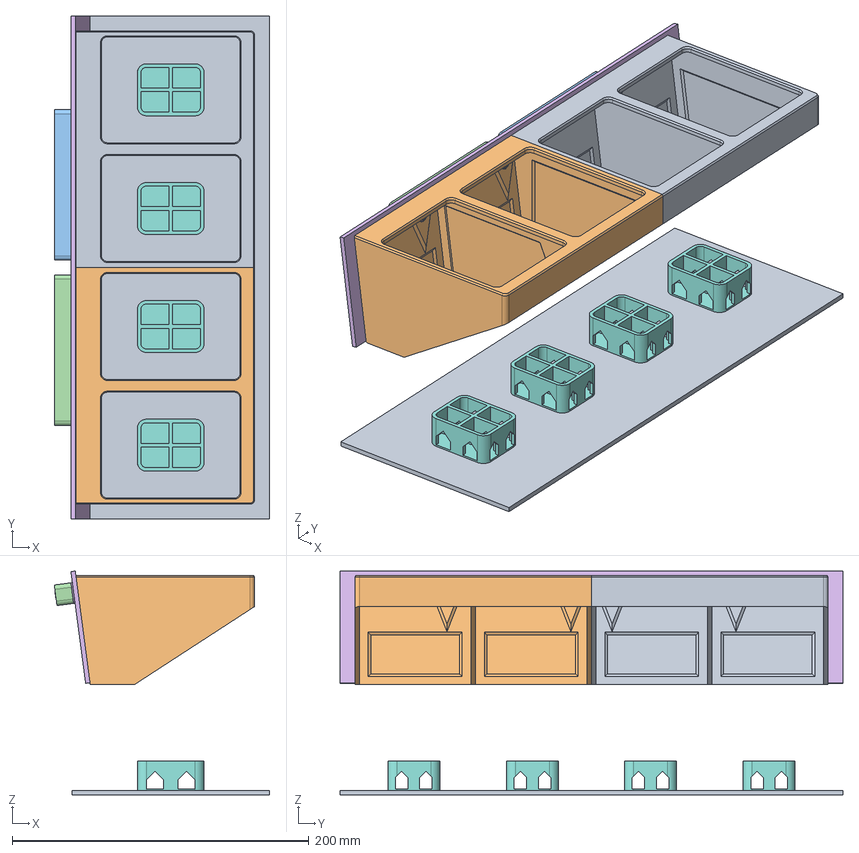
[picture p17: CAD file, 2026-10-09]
bottle-holder/cad/THD_CP_Lift_Bottle_Holder.FCStd
145.2 x 339.0 x 150.9 mm
Module
Module mirrored
Nut bar
Nut bar mirrored
Gasket (TPU, print 2)
Gasket mirrored
M4x20-Screw
M4-Nut
M4x20-Screw031
M4-Nut028
M4x20-Screw032
M4-Nut029
M4x20-Screw033
M4-Nut030
Bath wall (reference) x 2
Bottle_Stand (TPU) x 4
Bath floor (reference)
Bath_Hole1
Bath_Hole2
Bath_Hole1_M
Bath_Hole2_M
Bath_Wall_Slab
Bath_Holes

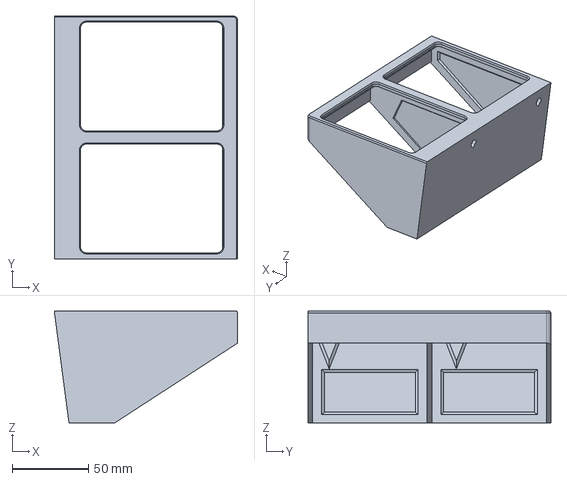
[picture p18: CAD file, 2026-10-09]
bottle-holder/step/THD_CP_Lift_Holder_Module.step
120.4 x 159.5 x 73.5 mm

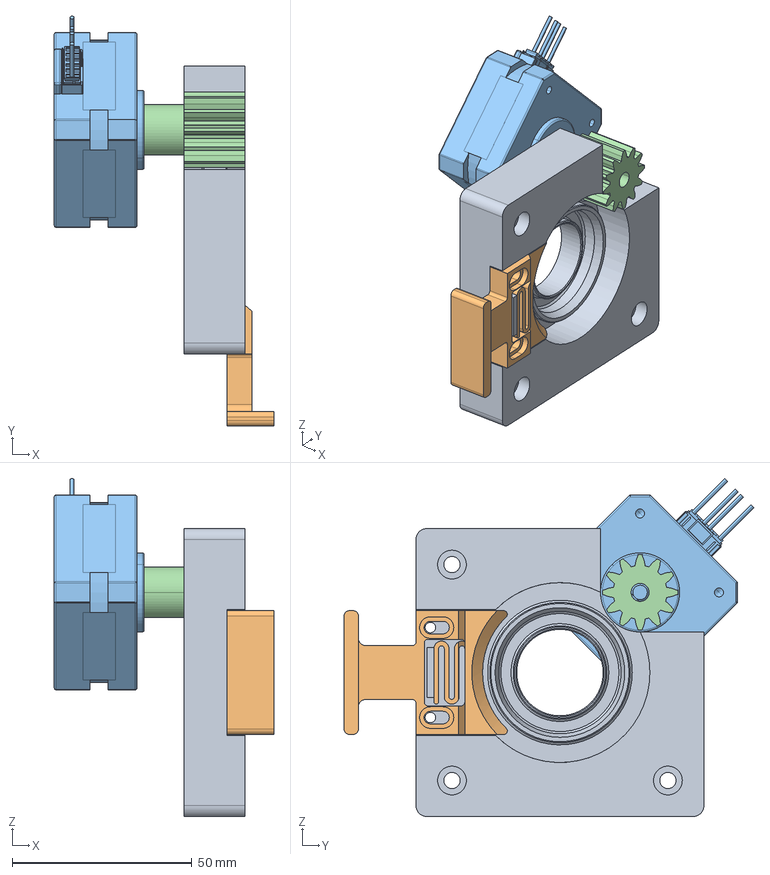
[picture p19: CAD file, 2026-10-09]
drum-mount/cad/JoboDrumMount.FCStd
61.0 x 113.9 x 93.9 mm
Mount
Lock
17HE08-1004S
7802-1,5-12-GR

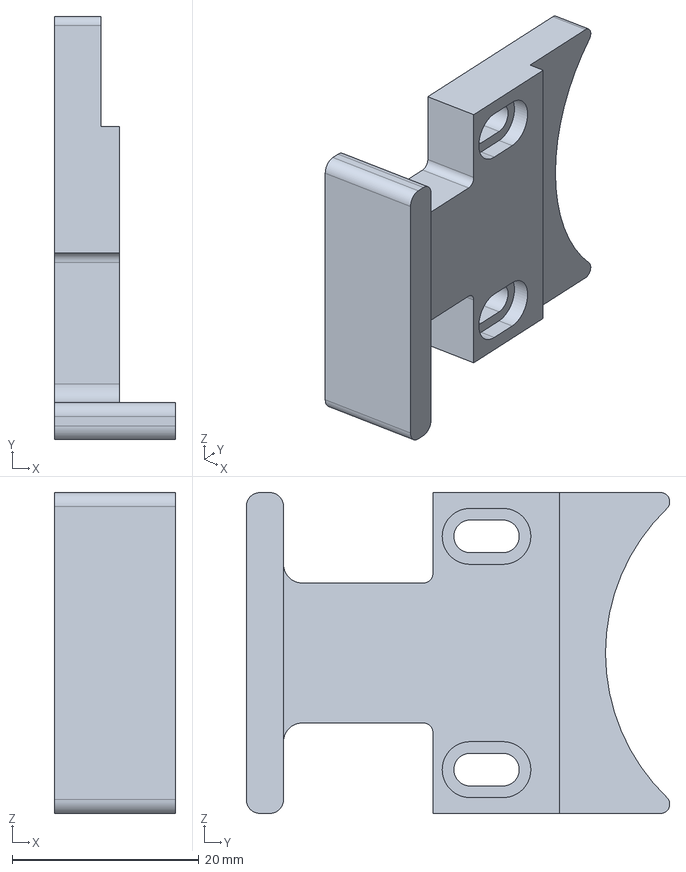
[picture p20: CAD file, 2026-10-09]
drum-mount/step/JoboDrumMount_Lock.step
13.0 x 45.4 x 34.4 mm

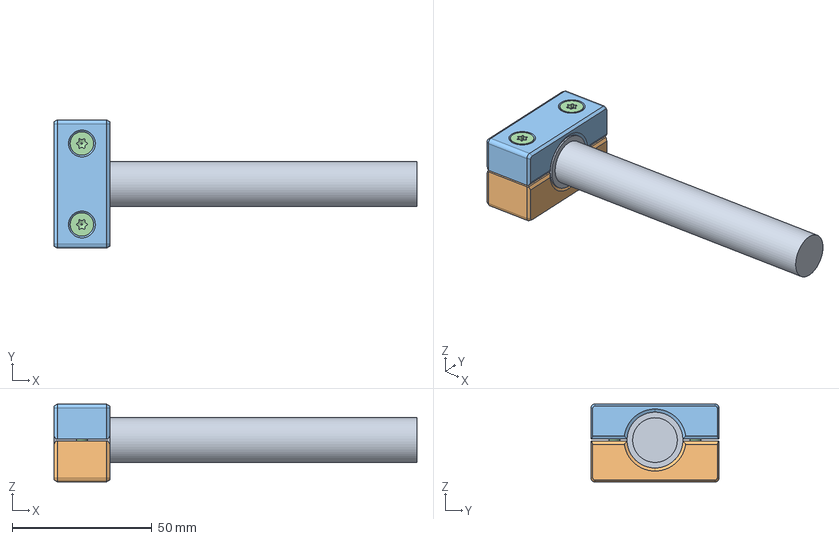
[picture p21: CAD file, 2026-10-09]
heater-holder/cad/THD_Heater_Holder.FCStd
130.0 x 46.0 x 27.9 mm
Heater
Base
Cap
M4x25-Screw x 2

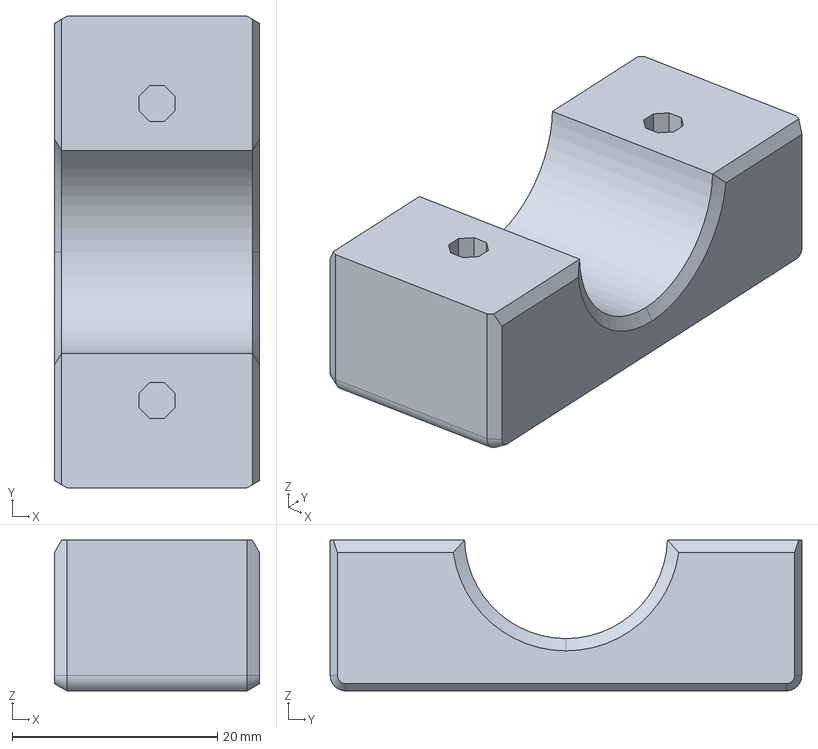
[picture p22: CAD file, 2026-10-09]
heater-holder/step/THD_Heater_Holder_Base.step
20.0 x 46.0 x 14.7 mm

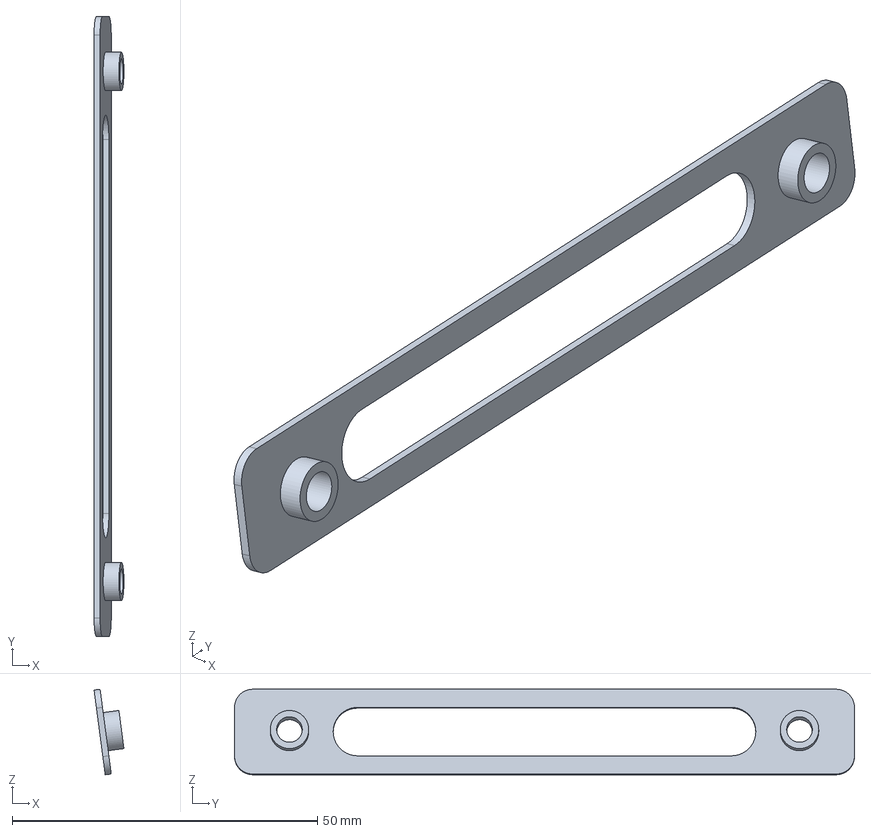
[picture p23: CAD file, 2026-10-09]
bottle-holder/step/THD_CP_Lift_Gasket_TPU.step
4.89 x 101.5 x 14.0 mm

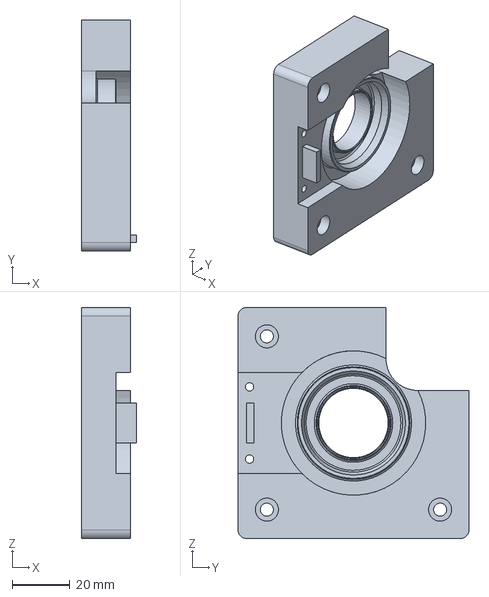
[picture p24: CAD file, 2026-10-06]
drum-mount/step/JoboDrumMount_Mount.step
19.0 x 80.0 x 80.0 mm

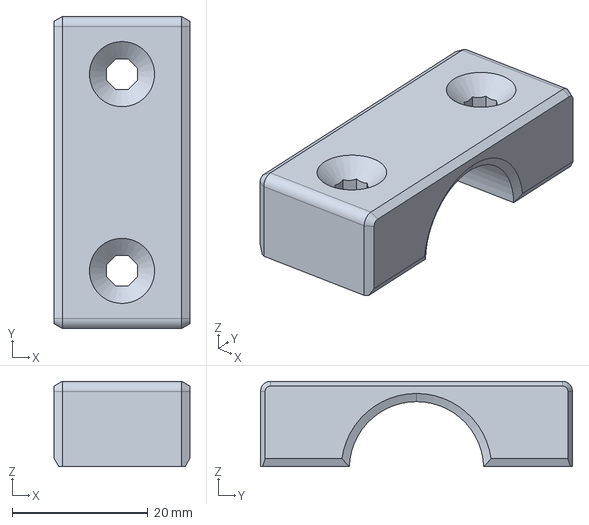
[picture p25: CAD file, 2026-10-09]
heater-holder/step/THD_Heater_Holder_Cap.step
20.0 x 46.0 x 12.6 mm

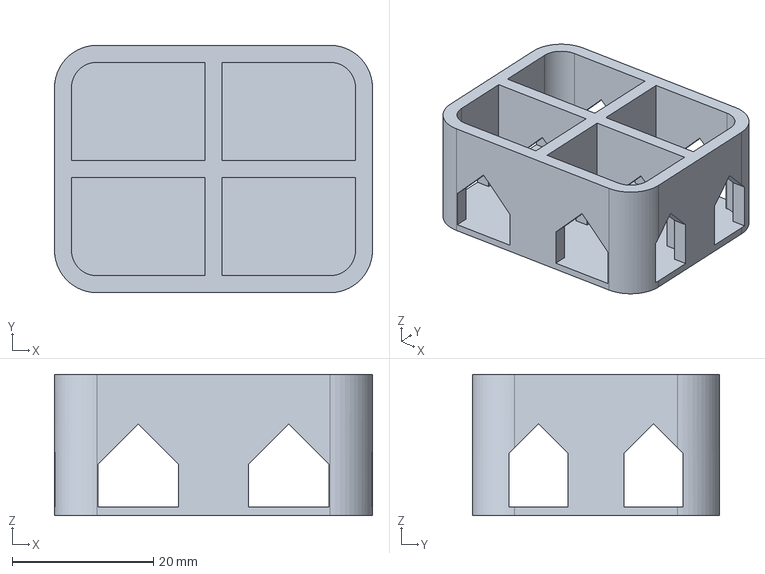
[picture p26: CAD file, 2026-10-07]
bottle-holder/step/THD_CP_Lift_Bottle_Stand_TPU.step
45.0 x 35.0 x 20.0 mm

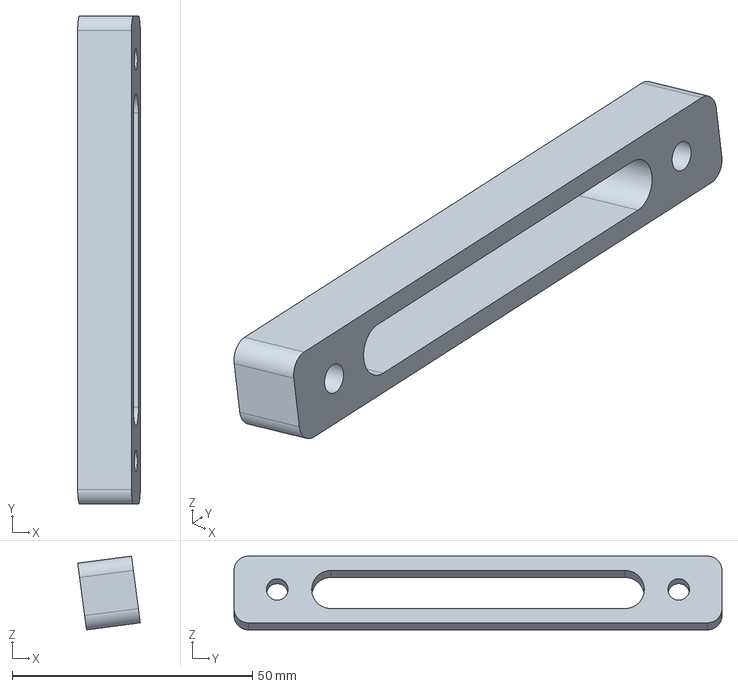
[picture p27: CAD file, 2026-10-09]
bottle-holder/step/THD_CP_Lift_Nut_Bar.step
13.0 x 101.5 x 15.4 mm

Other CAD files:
bottle-holder/step/THD_CP_Lift_Holder_Module_Mirrored.step

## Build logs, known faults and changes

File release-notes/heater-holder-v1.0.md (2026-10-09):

# THD heater holder v1.0 — ABS clamp

A two-part clamp for the 220 V THD bath heater. The base is glued to the bath floor; an M4-screwed cap holds the rubber heater head horizontally with its axis 15 mm above the floor. The parts are designed as symmetric, fully parametric FreeCAD bodies.

<p align="center">ABS heater clamp, cap lifted above baseHeater clamp bore and screw holes</p>

## Download

- [Complete v1.0 ZIP — FreeCAD model, STEP files, build script, pictures, instructions, and license](https://github.com/sasha-nordiclab/thd-cp-lift-parts/releases/download/heater-holder-v1.0/heater-holder-v1.0.zip)
- [Base STEP](https://github.com/sasha-nordiclab/thd-cp-lift-parts/releases/download/heater-holder-v1.0/THD_Heater_Holder_Base.step) · [Cap STEP](https://github.com/sasha-nordiclab/thd-cp-lift-parts/releases/download/heater-holder-v1.0/THD_Heater_Holder_Cap.step)
- [Parametric FreeCAD model](https://github.com/sasha-nordiclab/thd-cp-lift-parts/releases/download/heater-holder-v1.0/THD_Heater_Holder.FCStd)

## Design

- Base: 46 × 20 mm glue footprint, 14.7 mm high, with a half-round bed and two blind octagonal pilot holes.
- Cap: a 46 × 20 × 12.6 mm block with a half-round bore, two octagonal clearance holes, and flush 90° countersinks.
- Two M4 × 25 ISO 14581 countersunk Torx screws, at ±14.5 mm from the heater axis, form threads in the base pilot holes. The split has a 0.6 mm gap before tightening.
- Rounded R1.5 outer corners and chamfered end faces help with ABS printing. The base and cap STEP exports were regenerated from the current CAD solids and checked for valid single-solid geometry. All seven sketches have zero free degrees of freedom.

## Printing and status

Use ABS (the model was prepared for AzureFilm ABS Plus), 0.4 mm nozzle, 0.6 mm line width, 0.2 mm layers, and 100% rectilinear infill. Print each part on an end face with a brim. OrcaSlicer estimates on a Bambu Lab A1 are about 36 min / 10.2 g for the base and 32 min 30 s / 7.9 g for the cap. These are slicer estimates; this design has **not been print-tested**.

See the [full model and assembly notes](https://github.com/sasha-nordiclab/thd-cp-lift-parts/blob/heater-holder-v1.0/heater-holder/README.md). The FCStd file uses a FreeCAD 26.3 development build. Licensed under [CC BY-NC-SA 4.0](https://github.com/sasha-nordiclab/thd-cp-lift-parts/blob/heater-holder-v1.0/LICENSE).

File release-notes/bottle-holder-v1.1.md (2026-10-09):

# THD CP-Lift bottle holder v1.1

The current two-module frame holds four standard JOBO bottles in the THD CP-Lift water bath. **This release includes both mirrored frame modules**, the matching nut bar and gasket, four-bottle assembly model, and TPU bottle stands.

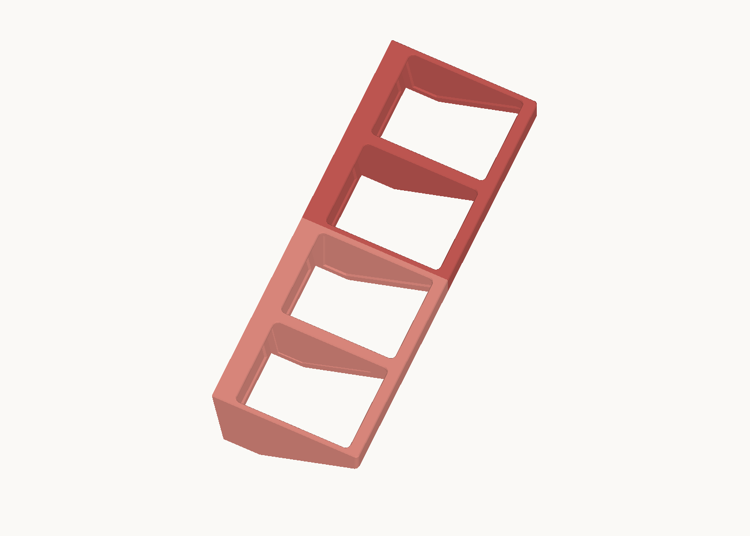
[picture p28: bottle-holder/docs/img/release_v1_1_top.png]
Frame openings viewed from above
<p align="center">Current four-bottle frame</p>

## Download

- [Complete v1.1 ZIP — FreeCAD model, all STEP files, documentation, pictures, and license](https://github.com/sasha-nordiclab/thd-cp-lift-parts/releases/download/bottle-holder-v1.1/bottle-holder-v1.1.zip)
- [Module STEP](https://github.com/sasha-nordiclab/thd-cp-lift-parts/releases/download/bottle-holder-v1.1/THD_CP_Lift_Holder_Module.step) · [Mirrored module STEP](https://github.com/sasha-nordiclab/thd-cp-lift-parts/releases/download/bottle-holder-v1.1/THD_CP_Lift_Holder_Module_Mirrored.step)
- [Nut bar STEP](https://github.com/sasha-nordiclab/thd-cp-lift-parts/releases/download/bottle-holder-v1.1/THD_CP_Lift_Nut_Bar.step) · [TPU gasket STEP](https://github.com/sasha-nordiclab/thd-cp-lift-parts/releases/download/bottle-holder-v1.1/THD_CP_Lift_Gasket_TPU.step) · [TPU bottle stand STEP](https://github.com/sasha-nordiclab/thd-cp-lift-parts/releases/download/bottle-holder-v1.1/THD_CP_Lift_Bottle_Stand_TPU.step)
- [Parametric FreeCAD model](https://github.com/sasha-nordiclab/thd-cp-lift-parts/releases/download/bottle-holder-v1.1/THD_CP_Lift_Bottle_Holder.FCStd)

## Changes since v1.0

- Updated the two frame modules with the bed-side chamfer and rounded outside corner. The openings remain 93.4 × 71.4 mm with R4 corners; each module is about 120.4 × 159.5 × 74.7 mm.
- Corrected the M4 hole layout: the pair across the module joint is 27.8 mm centre to centre. The matching nut bar and gasket STEP files are included.
- Added the TPU bottle stand to the downloadable set. Four stands support the bottles above the bath floor and leave water paths underneath.
- Updated the complete FreeCAD assembly. All 25 sketches are fully constrained, and the five STEP files were checked against their corresponding final CAD solids.

## Printing and assembly

| Part | Quantity | Material | Orientation and slicer estimate |
|---|---:|---|---|
| Module + mirrored module | 1 + 1 | PETG | Frame face down; 5 walls, 100% rectilinear; about 3 h 05 min and 126 g each |
| Nut bar | 2 | PETG | Bath side down, nut pockets up; about 32 min and 11 g each |
| Gasket | 2 | TPU 95A | Flat, sleeves up |
| Bottle stand | 4 | TPU 95A | Glue face down; about 1 h 16 min and 11 g each |

Use four M4 × 20 countersunk Torx screws (ISO 14581, stainless 304) and four M4 nuts (ISO 4032). The holder mounts through the 3 mm bath wall; the gasket sits between the wall and each nut bar. See the [assembly and printing instructions](https://github.com/sasha-nordiclab/thd-cp-lift-parts/blob/bottle-holder-v1.1/bottle-holder/README.md).

The [FEM design report](https://github.com/sasha-nordiclab/thd-cp-lift-parts/blob/bottle-holder-v1.1/bottle-holder/docs/report.md) describes the earlier frame. FEM was **not rerun** after the latest hole layout and chamfer changes. The model was made with a FreeCAD 26.3 development build; STEP files can be used without that version. Licensed under [CC BY-NC-SA 4.0](https://github.com/sasha-nordiclab/thd-cp-lift-parts/blob/bottle-holder-v1.1/LICENSE).

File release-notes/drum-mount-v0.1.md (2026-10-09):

# JOBO drum mount v0.1 — experimental

An experimental two-part JOBO drum mount for the THD CP-Lift: an 80 × 80 mm mounting plate with locating rings and a sliding lock with a printed spring. Pull the finger ears to release the drum; the lock travel is 3.5 mm.

<p align="center">Drum mount and sliding lockDrum mount and lock from above</p>

## Download

- [Complete v0.1 ZIP — FreeCAD model, both STEP files, pictures, instructions, and license](https://github.com/sasha-nordiclab/thd-cp-lift-parts/releases/download/drum-mount-v0.1/drum-mount-v0.1.zip)
- [Mount STEP](https://github.com/sasha-nordiclab/thd-cp-lift-parts/releases/download/drum-mount-v0.1/JoboDrumMount_Mount.step) · [Lock STEP](https://github.com/sasha-nordiclab/thd-cp-lift-parts/releases/download/drum-mount-v0.1/JoboDrumMount_Lock.step)
- [Parametric FreeCAD model](https://github.com/sasha-nordiclab/thd-cp-lift-parts/releases/download/drum-mount-v0.1/JoboDrumMount.FCStd)

## Design and assembly

| Part | Approximate size | Function |
|---|---|---|
| Mount | 80 × 80 × 19 mm | Locates the drum with rings, a Ø24 mm centre bore, and a motor pocket |
| Lock | 45 × 34 × 13 mm | Sliding latch with a spring and finger ears; the STEP file contains the final mirrored lock shape |

Three M4 cap screws mount the plate to the lift through Ø4.5 mm holes with Ø8 mm counterbores. Two M3 screws attach the lock through its slots into Ø2.9 mm pilot holes in the mount. The FreeCAD file includes the parametric model and an assembly showing the parts together. All saved sketches have zero free degrees of freedom; the exported lock is one valid solid and matches the `LockMirror` feature.

Both pieces are intended to print flat in PETG without supports. Earlier OrcaSlicer estimates on a Bambu Lab A1 were about 2 h / 60 g for the Mount at 40% cubic infill and about 25 min / 8 g for the Lock. Re-slice the supplied STEP files for current times and material use.

**Work in progress:** the geometry may change, and this mount has not been strength-checked. See the [full printing and assembly notes](https://github.com/sasha-nordiclab/thd-cp-lift-parts/blob/drum-mount-v0.1/drum-mount/README.md). The FCStd file uses a FreeCAD 26.3 development build. Licensed under [CC BY-NC-SA 4.0](https://github.com/sasha-nordiclab/thd-cp-lift-parts/blob/drum-mount-v0.1/LICENSE).

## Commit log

2026-10-06 THD CP-Lift bottle holder: parametric model, STEP, strength notes
    Two-bottle module for 600 ml square bottles on a THD CP-Lift, plus its
    mirror. Parametric FreeCAD model (spreadsheet params), STEP exports,
    FEM method and results, CC BY-NC-SA 4.0.
    [THD_CP_Lift_Bottle_Holder.FCStd, THD_CP_Lift_Holder_Module.step, THD_CP_Lift_Holder_Module_Mirrored.step]
2026-10-06 Restructure as jobo-thd-cp-lift-parts; add the JOBO drum mount
    - bottle-holder/: the THD CP-Lift bottle holder (moved)
    - drum-mount/: JOBO drum mount (Mount plate + Lock with printed spring),
    parametric FreeCAD model, STEP, README; empty placeholder body removed
    - top-level README with the part list and common notes
    [JoboDrumMount.FCStd, JoboDrumMount_Lock.step, JoboDrumMount_Mount.step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]
2026-10-06 Bottle holder: description, video playlist, nut bar and screw length
    - optimised redesign for the THD CP-Lift, four standard JOBO bottles
    - printed nut bar (STEP + model) for the outside of the 3 mm bath wall
    - mounting: M4 x 14 stainless countersunk + ISO 4032 nuts, stack table
    - link to the YouTube playlist
    [THD_CP_Lift_Bottle_Holder.FCStd, THD_CP_Lift_Holder_Module.step, THD_CP_Lift_Holder_Module_Mirrored.step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]
2026-10-06 Bottle holder: M4 x 20 Torx screws, nut bar sized to the screw
    [THD_CP_Lift_Bottle_Holder.FCStd, THD_CP_Lift_Holder_Module.step, THD_CP_Lift_Holder_Module_Mirrored.step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]
2026-10-06 Nut bar: through slot between the nuts
    [THD_CP_Lift_Bottle_Holder.FCStd, THD_CP_Lift_Holder_Module.step, THD_CP_Lift_Holder_Module_Mirrored.step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]
2026-10-06 Bottle holder: TPU seals for the bath holes; frame flush with the mount plane
    [THD_CP_Lift_Bottle_Holder.FCStd, THD_CP_Lift_Holder_Module.step, THD_CP_Lift_Holder_Module_Mirrored.step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]
2026-10-06 Bottle holder: one flat tilted mount face
    [THD_CP_Lift_Bottle_Holder.FCStd, THD_CP_Lift_Holder_Module.step, THD_CP_Lift_Holder_Module_Mirrored.step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]
2026-10-06 Bottle holder: bigger seal groove, confined TPU seal
    [THD_CP_Lift_Bottle_Holder.FCStd, THD_CP_Lift_Holder_Module.step, THD_CP_Lift_Holder_Module_Mirrored.step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]
2026-10-06 Bottle holder: seal moved under the nut bar; holder strength unchanged
    [THD_CP_Lift_Bottle_Holder.FCStd, THD_CP_Lift_Holder_Module.step, THD_CP_Lift_Holder_Module_Mirrored.step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]
2026-10-06 Bottle holder: flat TPU gasket under the nut bar
    [THD_CP_Lift_Bottle_Holder.FCStd, THD_CP_Lift_Gasket_TPU.step, THD_CP_Lift_Holder_Module.step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]
2026-10-06 Bottle holder: bath wall tilt parameter, assembly views
    [THD_CP_Lift_Bottle_Holder.FCStd, THD_CP_Lift_Gasket_TPU.step, THD_CP_Lift_Holder_Module.step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]
2026-10-06 Bottle holder: design report with FEM (full-face contact), screw forces and deformation pictures
2026-10-06 READMEs: assembly views, exploded view and FEM deformation pictures
2026-10-06 Bottle holder v1.0 release; drum mount marked experimental, work in progress
2026-10-07 Bottle holder: TPU bottle stands glued to the bath floor; assembly with Fasteners screws and nuts in the model
    [THD_CP_Lift_Bottle_Holder.FCStd, THD_CP_Lift_Bottle_Stand_TPU.step]
2026-10-08 Heater holder: PETG clamp for the 220 V bath heater
    New part folder: base glued to the bath floor and a cap screwed down
    with two M4 x 16 ISO 14581 countersunk Torx screws into octagonal
    pilot holes. Parametric FreeCAD model built symmetric (one side plus
    PartDesign Mirrored), STEP of both parts, build script.
    [THD_Heater_Holder.FCStd, THD_Heater_Holder_Base.step, THD_Heater_Holder_Cap.step]
2026-10-08 Heater holder: modelled as one half profile and one mirror per part
    Each part is a fully constrained +Y half-profile sketch, a symmetric
    pad, the +Y screw hole and end chamfers, then one PartDesign Mirrored
    of the whole shape. Same geometry; STEP refreshed.
    [THD_Heater_Holder.FCStd, THD_Heater_Holder_Base.step, THD_Heater_Holder_Cap.step]
2026-10-08 Downloads: direct links to every STEP, FCStd and release zip
    A Downloads table at the top of the main README and a Download line at
    the top of each part README, so the print files are one click away.
2026-10-09 Link shared ROTEK A01VP pump project
2026-10-09 Sync latest THD CP-Lift models and STEP exports
    [JoboDrumMount.FCStd, JoboDrumMount_Lock.step, THD_CP_Lift_Bottle_Holder.FCStd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]
2026-10-09 Promote heater holder release to v1.0
